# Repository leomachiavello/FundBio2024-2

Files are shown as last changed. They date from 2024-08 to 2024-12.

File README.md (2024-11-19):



# Fundamentos de Biodiseño - Equipo 08

## Descripción del curso
En el curso de Fundamentos de Biodiseño el estudiante será introducido a los métodos de diseño y desarrollo de tecnologías innovadoras con la finalidad de resolver una problemática que afecta a nuestra sociedad.
## 📋 Entregables
- [Entregable 1](https://github.com/leomachiavello/FundBio2024-2/blob/main/Entregables/Entregable_1.md)
- [Entregable 2](https://github.com/leomachiavello/FundBio2024-2/blob/main/Entregables/Entregable_2.md)
- [Entregable 3](https://github.com/leomachiavello/FundBio2024-2/blob/main/Entregables/Entregable_3.md)
- [Entregable 4](https://github.com/leomachiavello/FundBio2024-2/blob/main/Entregables/Entregable_4.md)
- [Entregable 5](https://github.com/leomachiavello/FundBio2024-2/blob/main/Entregables/Entregable_5.md)
- [Entregable 6](https://github.com/leomachiavello/FundBio2024-2/blob/main/Entregables/Entregable_6.md)
- [Entregable 7](https://github.com/leomachiavello/FundBio2024-2/blob/main/Entregables/Entregable_7.md)
- [Entregable 8](https://github.com/leomachiavello/FundBio2024-2/blob/main/Entregables/Entregable_8.md)
- [Entregable 9](https://github.com/leomachiavello/FundBio2024-2/blob/main/Entregables/Entregable_9.md)
## 👨‍🎓 Integrantes del equipo
### Leonardo Fabrizio Machiavello Díaz. **Coordinador General**
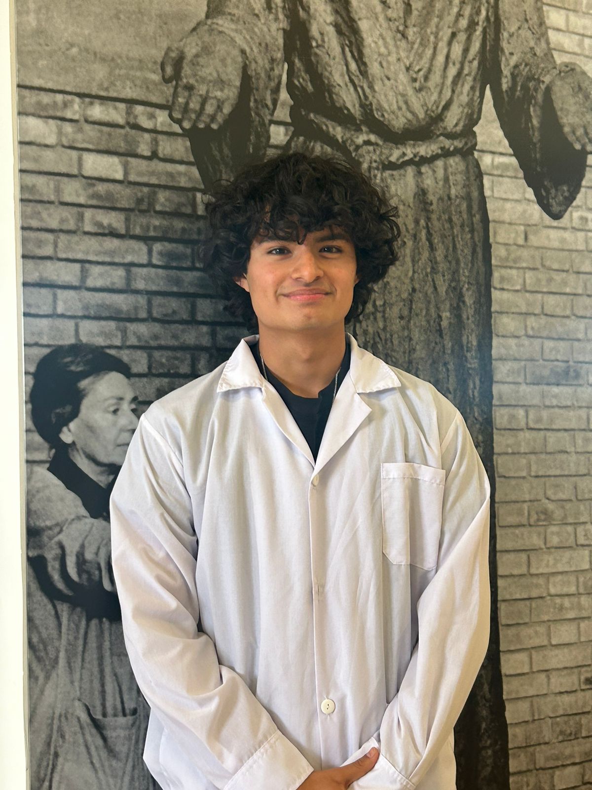
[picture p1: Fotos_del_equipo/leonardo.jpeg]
>

Estudiante de Ing. Biomédica con interés en la ingeniería clínica y el diseño industrial. Encargado de organizar al equipo asegurándose de que estén cumpliendo su deber, al igual que estar pendiente de que se cumplan las tareas del proyecto.

### Ana Paula Vela Velásquez. **Diseño 3D**
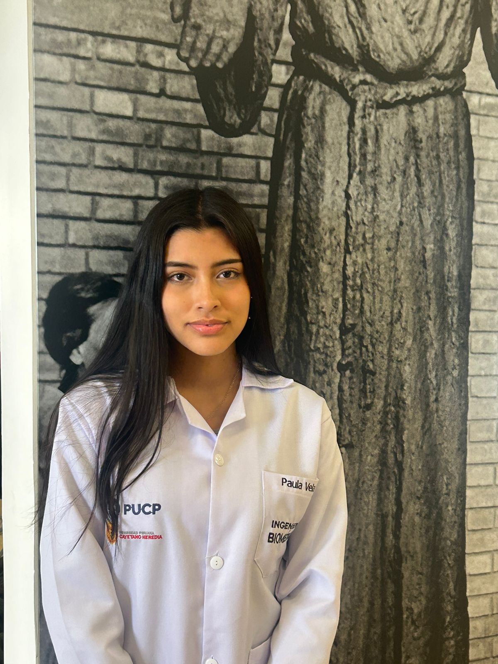
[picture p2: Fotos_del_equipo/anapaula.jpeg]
>

Estudiante de Ing. Biomédica con interés en la biomecánica aplicada para la rehabilitación.
Encargada de usar software enfocado en modelar diseños tridimensionales para aplicarlos a nuestro producto final.

### Luis Fernando Pingo Juárez. **Prototipado Electrónico**
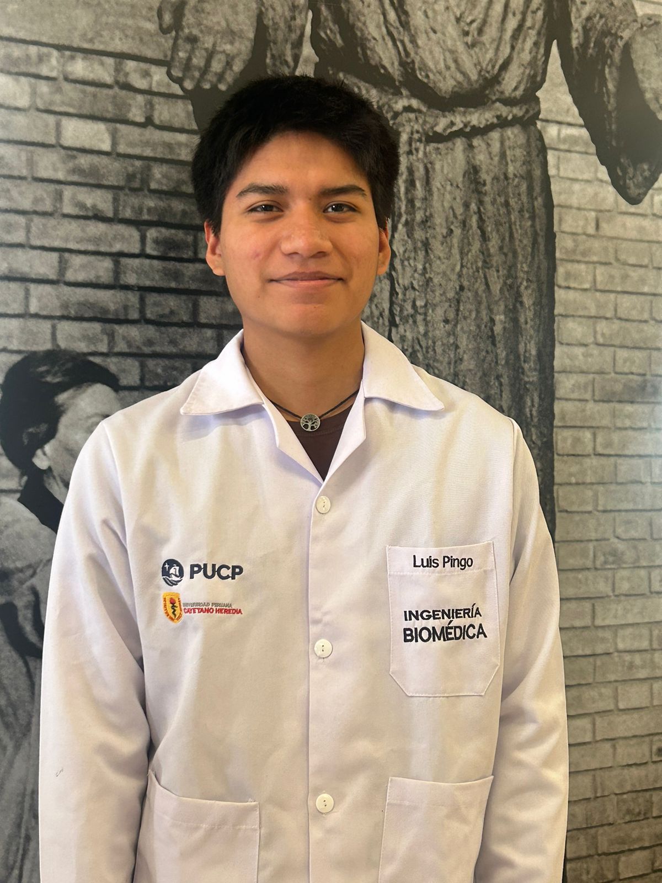
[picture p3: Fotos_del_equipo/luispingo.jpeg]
>

Estudiante de Ing. Biomédica con interés en la ingeniería de tejidos y . Encargado de desarrollar y construir prototipos de circuitos y dispositivos electrónicos, además de estar pendiente a la selección de componentes y el montaje de prototipos.

### Mateo Torres Ricalde. **Diseño electrónico**
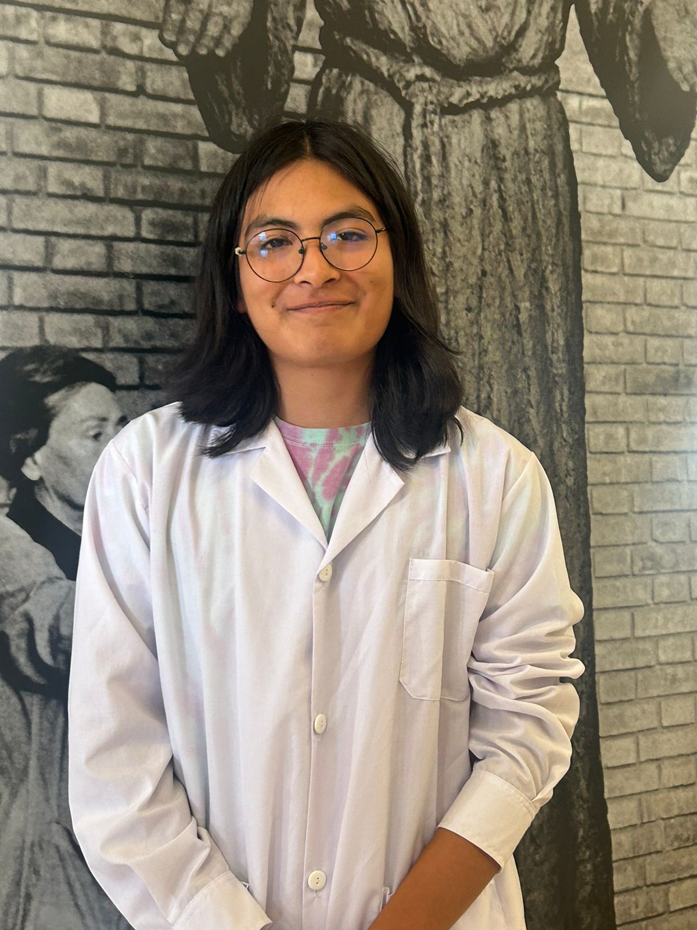
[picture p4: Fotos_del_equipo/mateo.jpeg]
>

Estudiante de Ing. Biomédica con interés en la biomecánica. Encargado de desarrollar el diseño y esquemas de los circuitos electrónicos utilizados, para conseguir la opción más adecuada al proyecto.

### Pedro Alonso Calderón Hidalgo. **Manufactura digital**
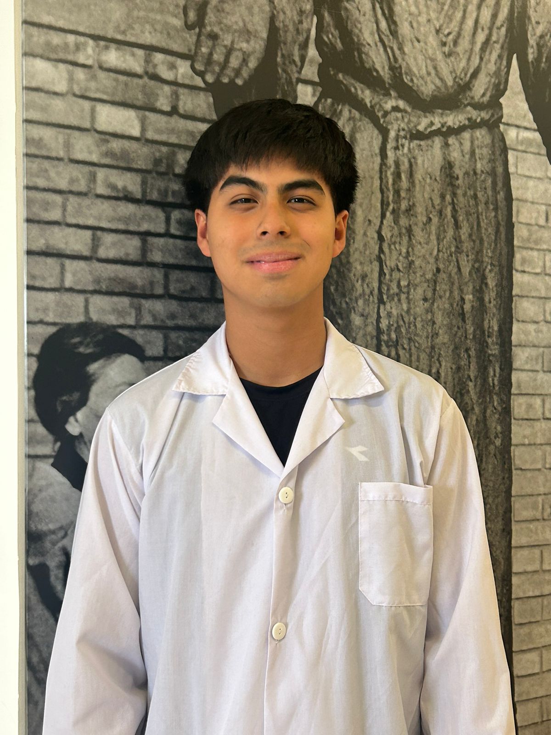
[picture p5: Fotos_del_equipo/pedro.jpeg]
>

Estudiante de Ingeniería Biomédica interesado en biomecánica y en mejorar dispositivos médicos. Diseña y produce prototipos con impresión 3D, asegurando precisión en especificaciones, gestionando manufactura y colaborando con el equipo de investigación.

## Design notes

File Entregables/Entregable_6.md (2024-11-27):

# Esquema electrónico final
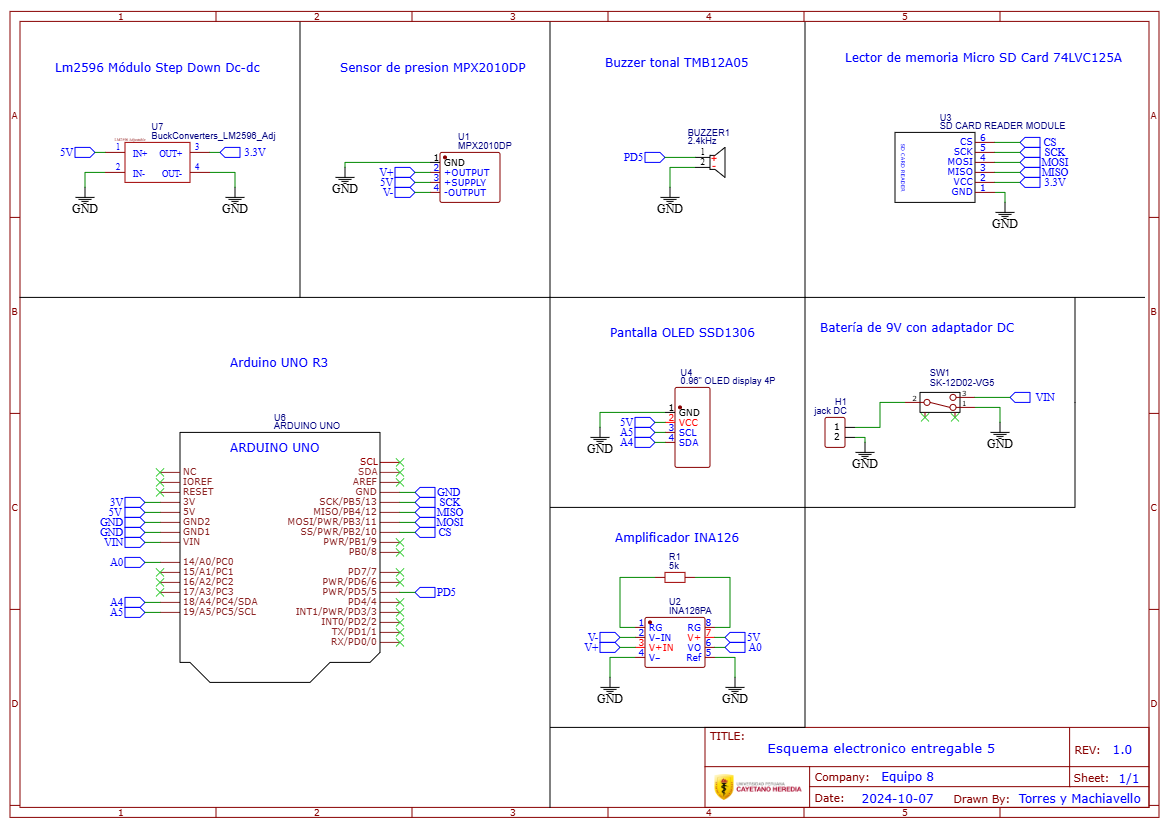
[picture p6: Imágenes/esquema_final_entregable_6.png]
esquema_final

# Ejecución del código Arduino
A partir del código mostrado en el siguiente inciso, hicimos una prueba usando los componentes básicos (sensor de presión, buzzer y amplificador). A partir de esto pudimos imprimir los datos de voltaje en el monitor serial del Arduino IDE, lo que nos permitió observar el cambio de señales de acuerdo a la presión ejercida.

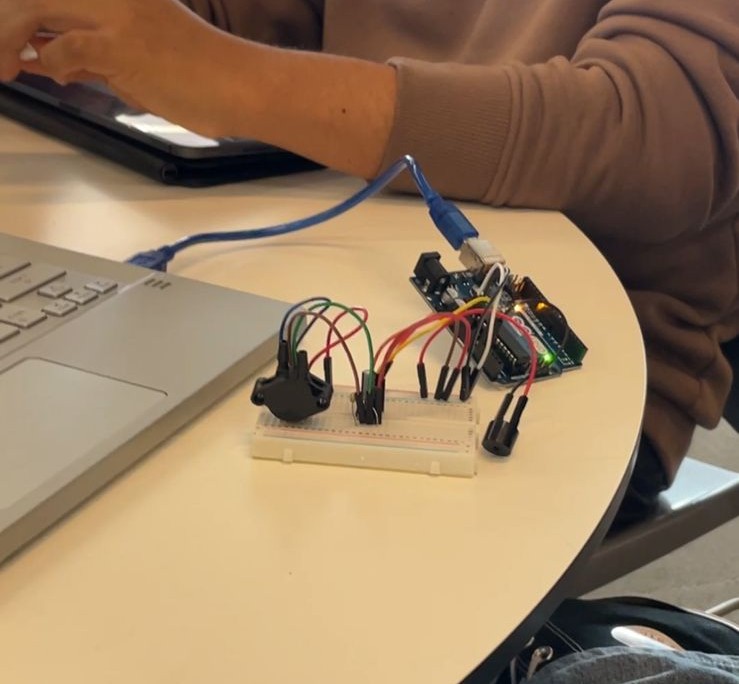
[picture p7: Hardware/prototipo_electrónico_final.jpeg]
prot_arduino

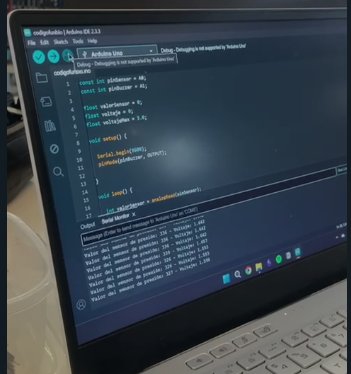
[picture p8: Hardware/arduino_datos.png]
datos_arduino

# Código Arduino
```
const int pinSensor = A0;
const int pinBuzzer = A1;

float valorSensor = 0;
float voltaje = 0;
float voltajeMax = 3.0;

void setup() {

  Serial.begin(9600);
  pinMode(pinBuzzer, OUTPUT);

}

void loop() {

  int valorSensor = analogRead(pinSensor);
  float voltaje = valorSensor * (5.0/1023.0);
  
  Serial.print("Valor del sensor de presión: ");
  Serial.print(valorSensor);
  Serial.print(" - Voltaje: ");
  Serial.println(voltaje, 3);

  if (voltaje >= voltajeMax){
    tone(buzzerPin, 1000);
  } else {
    noTone(buzzerPin);
  }

  delay(1000);

}
```
# Modelo 3D
## Vista explosionada
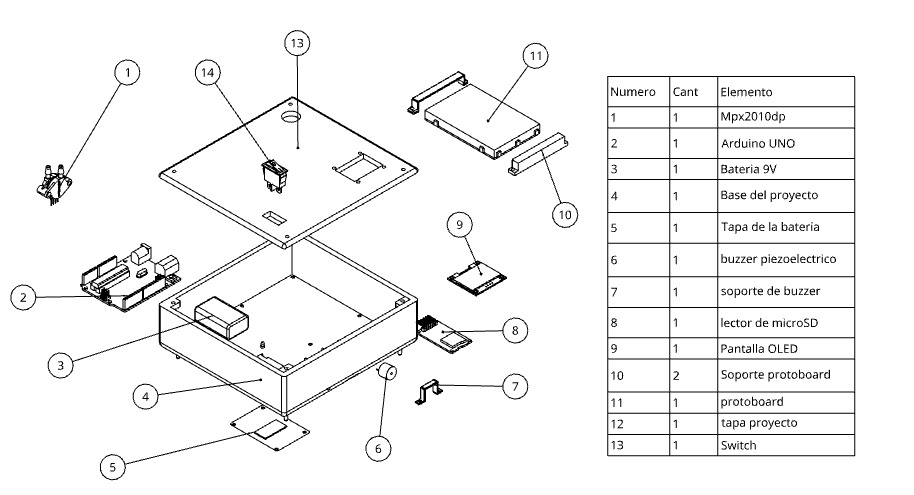
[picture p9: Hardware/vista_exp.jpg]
vista_exp

## Renderizados




# Diagrama de  flujo de datos (Arduino)
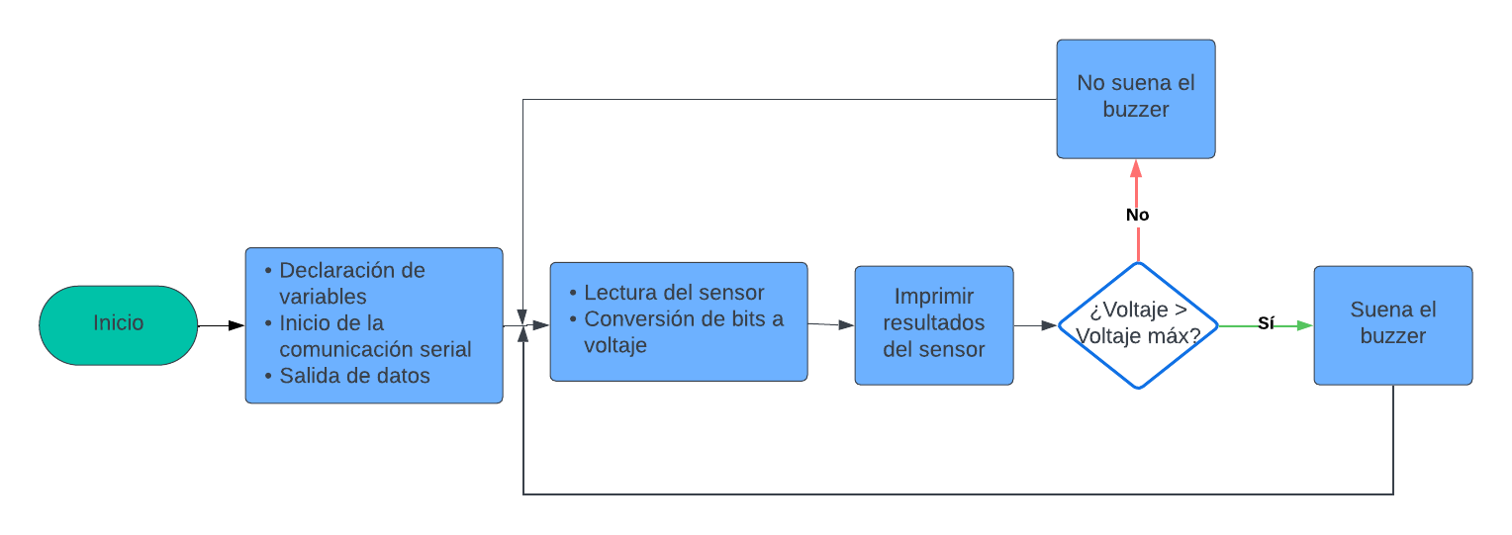
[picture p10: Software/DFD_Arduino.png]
DFD

# Reporte de pruebas
Funciones de los componentes:
-	Arduino Uno: se usa para procesar los datos recibidos por el sensor de presión diferencial y transformarlo en las variables que necesitamos.
-	Sensor de presión: mide la presión que ejerce el flujo de aire que es espirado por el paciente.
-	Buzzer: funciona como un indicador de que el procedimiento ha sido correcto o no.
-	Pantalla OLED: muestra información básica de los resultados del procedimiento.

Al evaluar la funcionalidad de los componentes que usaremos en el dispositivo, hemos verificado que la mayor parte de estos cumplen adecuadamente con su propósito, sin embargo, hemos identificado los siguientes aspectos en los que podemos mejorar:
-	Sensor de presión: es la pieza con más valor del prototipo, Además se tuvieron ciertas dificultades para poder implementarlo en el sistema, por lo que es necesario usarlo con cuidado para evitar dañar el componente y producir errores en la lectura.
-	Lector de tarjeta SD: es un componente difícil de conseguir en el país, por lo que se están evaluando otras posibilidades.
-	Regulador de voltaje (step down): Si bien fue considerado inicialmente como un componente importante, el lector de tarjeta SD tiene ya un regulador integrado, por lo que su uso termina siendo innecesario, lo que lleva a que este componente sea descartado del modelo final.

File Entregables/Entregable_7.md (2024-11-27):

# Esquema Electrónico
Esquema Final

# Ejecución del código Arduino 
Código usado en las pruebas para el sensor de presión. A partir de ello podemos transformar la presión ejercida a voltaje:
const int pinSensor1 = A0;
const int pinSensor2 = A1;

float valorSensor1 = 0;
float valorSensor2 = 0;

void setup() {
  
  Serial.begin(9600);
 
}

void loop() {

  int valorSensor1 = analogRead(pinSensor1);
  int valorSensor2 = analogRead(pinSensor2);

  Serial.print("Diferencia de presión: ");
  Serial.println(fabs(valorSensor1-valorSensor2));

  float voltaje = fabs(valorSensor1-valorSensor2) * (5.0/1023.0);
  Serial.print("Voltaje: ");
  Serial.print(voltaje * 1000, 3);
  Serial.println(" mV");

  float presion = voltaje / 0.009;
  Serial.print("Presión: ");
  Serial.print(presion);
  Serial.println(" kPa");

  delay(1000);

}
# Diagrama de flujo (Arduino)
Diagrama de flujo datos

# Reporte de pruebas
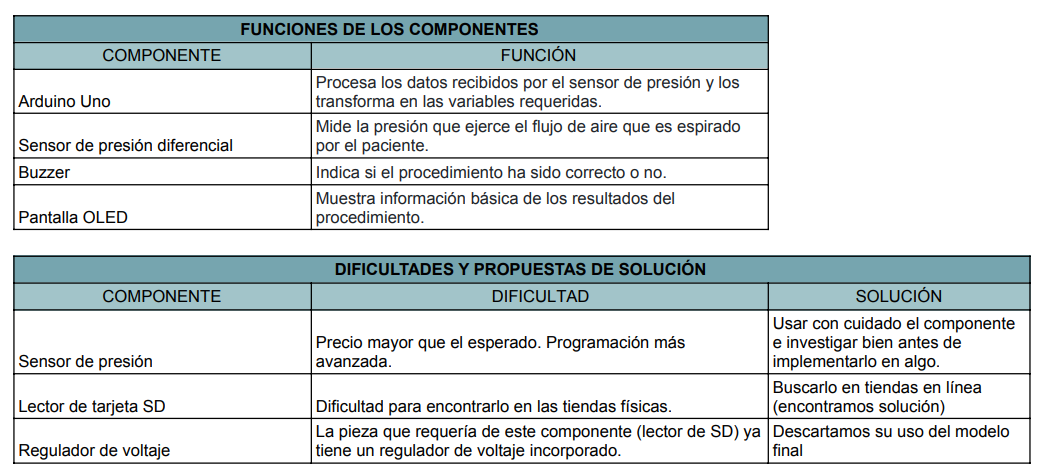
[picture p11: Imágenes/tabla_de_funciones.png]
tabla


# Impresión 3D
Base y tapa

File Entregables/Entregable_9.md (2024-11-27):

# Verificación de diseño (Software)

<table border="1">
  <tr>
    <th rowspan="2">Funcionalidad</th>
    <th colspan="2">Cumplimiento</th>
  </tr>
  <tr>
    <th>Sí</th>
    <th>No</th>
  </tr>
  <tr>
    <td>Recibe señales del sensor de presión</td>
    <td>X</td>
    <td></td>
  </tr>
  <tr>
    <td>Convierte las señales del sensor a presión</td>
    <td></td>
    <td>X</td>
  </tr>
  <tr>
    <td>Mide el tiempo de la prueba</td>
    <td>X</td>
    <td></td>
  </tr>
  <tr>
    <td>Genera un reporte rápido en la pantalla</td>
    <td>X</td>
    <td></td>
  </tr>
  <tr>
    <td>Genera un tabla con los datos en la tarjeta microSD</td>
    <td></td>
    <td>X</td>
  </tr>
</table>

# Verificación de diseño (Hardware)
| **Requerimiento de Diseño** | **Resultado del Test** |
|---|---|
| El dispositivo sumado al sistema de ajuste debe pesar máximo 300 gramos. | En suma de todos los componentes electrónicos el dispositivo cuenta con un peso de 260 gramos. |
| Debe tener una autonomía de 2 horas aproximadamente. | Con una batería de 9 voltios, se estima una duración aproximada de 10 horas tomando en cuenta el consumo de los elementos utilizados y el tiempo en que el dispositivo no es utilizado en ciclos de 32 minutos (2 de encendido, 30 de apagado). |
| Debe ser simple de usar para el usuario | El dispositivo cuenta con solo un switch de encendido y apagado. |
| Se debe seleccionar un sistema con boquilla desechable para que evitar contaminación en el dispositivo. | El sistema cuenta con una serie de boquillas desechables que permiten evitar cualquier tipo de contaminación. |
| El dispositivo de sonido buzzer proyecta un sonido a una frecuencia mayor o menor rango al señalizado por el Arduino Uno. | El dispositivo buzzer se activa a señal del Arduino Uno. |
| Mide la presión dada por la espiración del usuario. | El sensor de presión MPX2010DP mide la presión del usuario gracias a los amplificadores implementados |
| La interacción entre componentes se acciona mediante el protoboard y el Arduino Uno. | La interfaz entre los componentes otorga un resultado satisfactorio a través de la conexión con el protoboard señalizado al Arduino Uno. |
| El dispositivo es compacto y permite fácil transporte. | El dispositivo tiene unas dimensiones 157x147x49 mm que permiten su fácil transporte y un diseño compacto. |
| El dispositivo permite almacenar y transmitir datos. | El dispositivo permite almacenar datos gracias a la micro SD, transmitirlos gracias a la pantalla OLED y procesarlos gracias al Arduino Uno. |

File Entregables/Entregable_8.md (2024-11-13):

# Software
## [Códigos de prueba](https://github.com/leomachiavello/FundBio2024-2/tree/main/Software/c%C3%B3digos_prueba)
Agregamos códigos de prueba para cada componente electrónico (excluyendo el lector de tarjetas SD) con los cuales podemos realizar testeos. Estos se mostraron útiles sobre todo en la implementación de la pantalla de OLED y pruebas con la ganancia del amplificador INA126.
## [Borrador 1](https://github.com/leomachiavello/FundBio2024-2/tree/main/Software/borradores/borrador1)
Nuestra intención con este primer borrador fue la de integrar los principales componentes del proyecto. Hasta este punto todavía no teníamos la pantalla OLED, por lo que está excluída del código. Básicamente el código toma valores digitales del sensor y los pasa a voltaje haciendo uso de la ecuación $V=\frac{5.0}{1023.0}$ donde 5.0 representa el voltaje de la fuente y 1023.0 el número de bits máximo de la señal digital del Arduino. 
## [Borrador 2](https://github.com/leomachiavello/FundBio2024-2/tree/main/Software/borradores/borrador2)
En este segundo borrador implementamos la pantalla OLED junto a los demás componentes haciendo uso de librerías externas como Adafruit_GFX y Adafruit_SSD1306. En la pantalla OLED se muestran los valores de voltaje.
## [Borrador 3](https://github.com/leomachiavello/FundBio2024-2/tree/main/Software/borradores/borrador3)
En el tercer borrador implementamos un módulo en el código cuya función es la de promediar 10 valores en el lapso de un segundo de las señales amplificadas del sensor. Esto se hizo con el objetivo de reducir la variación de valores que se crea por el amplificador. 
## [Borrador 4](https://github.com/leomachiavello/FundBio2024-2/tree/main/Software/borradores/borrador4)
Finalmente en este borrador hemos juntado todo lo previamente mencionado e implementado un cronómetro que se activa al momento que el voltaje sobrepasa cierto límite. También en este código podemos generar un reporte del voltaje máximo y un promedio de los voltajes obtenidos para obtener información sobre la prueba.
## Parámetros de la espirometría
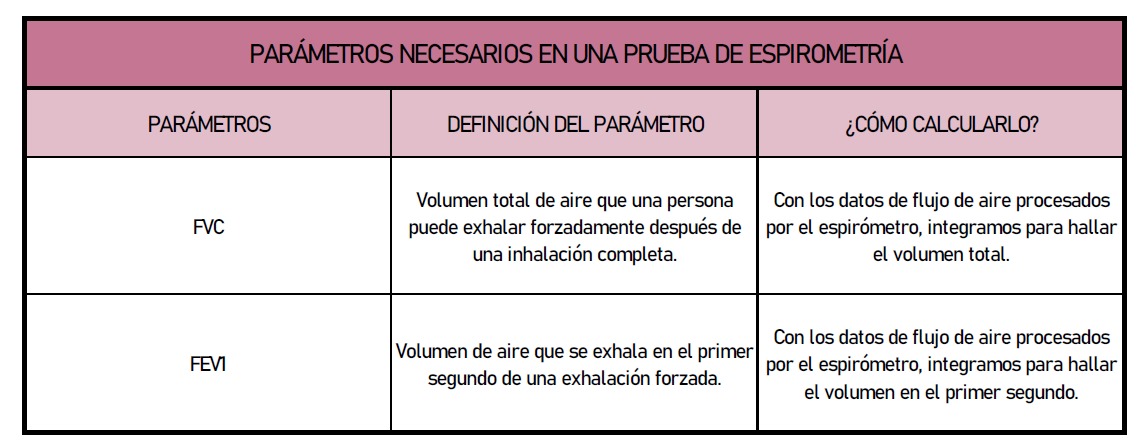
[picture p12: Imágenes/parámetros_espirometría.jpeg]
parámetros


Existen una serie de parámetros relacionados con la espirometría como el FVC, FEV6, FEV1 y PEF que sirven para detectar y clasificar enfermedades respiratorias. Entre los mencionados destacan el FVC y FEV1, ya que con estos se obtiene un índice con el que se clasifica una enfermedad respiratoria como obstructiva o restrictiva, lo que se ajusta a los objetivos de este proyecto.
# Hardware
## [Amplificador INA126](https://github.com/leomachiavello/FundBio2024-2/blob/main/Hardware/Datasheets/INA126_datasheet.pdf)
La fórmula de la ganancia de este amplificador en específico es la siguiente: 
$G=5+\frac{80k\Omega}{R_G}$. Actualmente la resistencia que estamos empleando para la ganancia es de $1k\Omega$ por lo que nuestra ganancia resultante es de 85. Aunque esta ganancia no es tan pequeña, tampoco es ideal para nuestro caso ya que el rango de voltajes del sensor se encuentra entre los 0 a 25mV, por lo que lo ideal será emplear una ganancia de 1000 que sea estable. Nuestras opciones de solución son las siguientes:
### Usar una resistencia menor 
Esta solución implicaría una mayor inestabilidad en la señal brindada por el amplificador, por lo que también se tendrían que implementar filtros de ruido usando capacitores y pequeños circuitos RC.
### Usar un amplificador extra
Esta solución sería un poco más costosa que la anterior, pero sería más simple. El amplificador que planeamos implementar es el **LM358**, el cual es económico y simple de usar. Para ajustar la ganancia se hace uso de dos resistencias, siguiendo la siguiente fórmula: $G=1+\frac{R_f}{R_{in}}$.
## Modelado 3D
Para este semana hemos logrado culminar al 100% nuestro modelo 3D, arreglamos las correciones indicadas por el profesor Andoni Molina y enviamos nuestras 5 piezas a imprimir, estamos a la espera que nos avisen para poder recogerlas. Acá tenemos algunas imagenes de nuestro modelo ensamblado, tenemos los [planos](https://github.com/leomachiavello/FundBio2024-2/tree/main/Hardware/Planos%20finales) de las 5 piezas corregidos y actualizados al igual que los [archivos stl](https://github.com/leomachiavello/FundBio2024-2/tree/main/Hardware/Archivos%20STL).
### Vistas isométricas del ensamblado
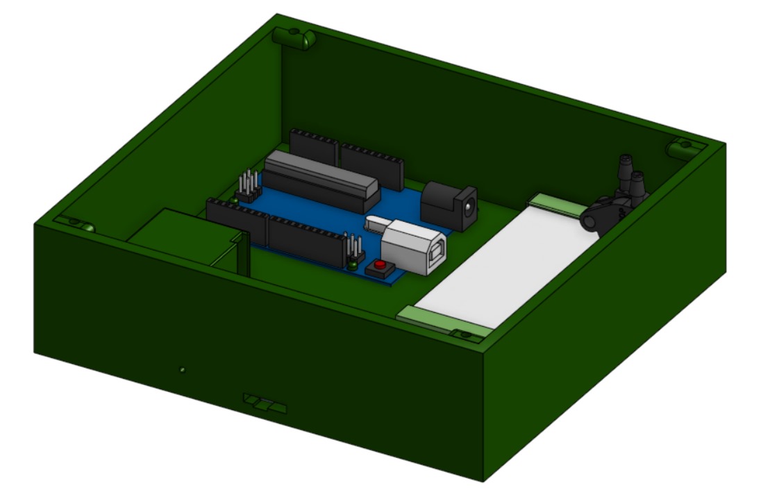
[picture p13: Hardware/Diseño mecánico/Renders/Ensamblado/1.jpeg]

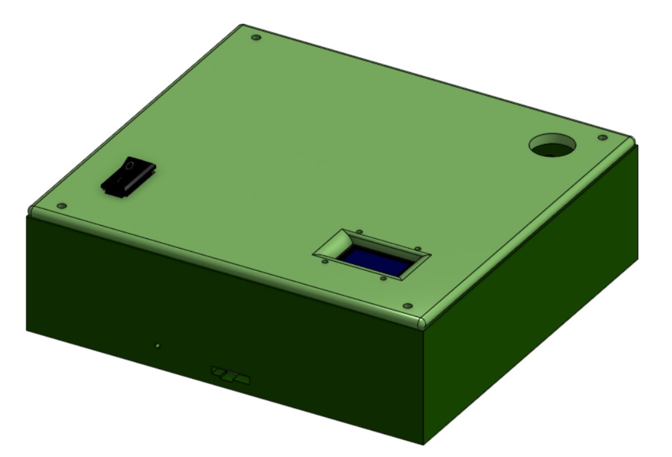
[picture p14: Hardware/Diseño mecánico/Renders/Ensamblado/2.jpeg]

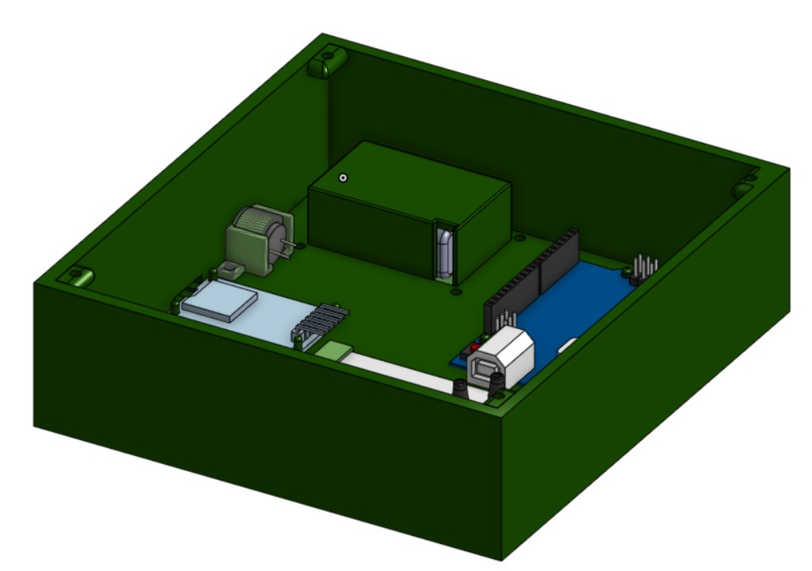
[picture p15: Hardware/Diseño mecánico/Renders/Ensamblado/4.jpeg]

### Vista superior
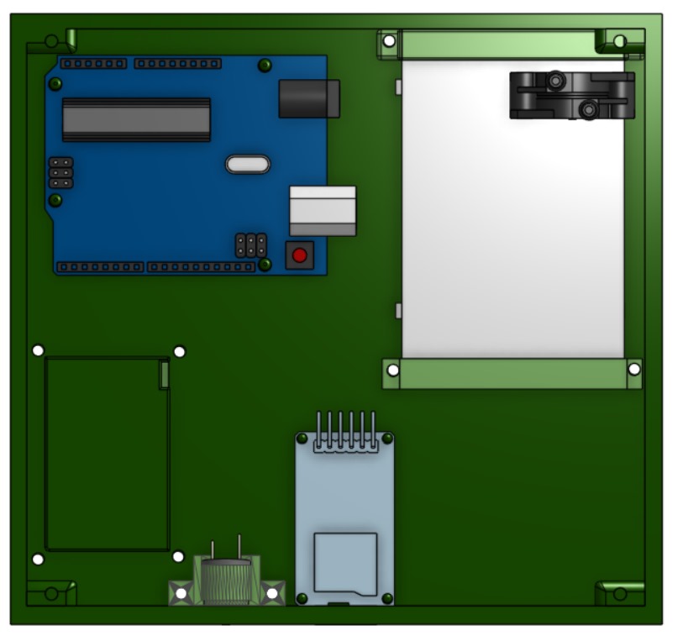
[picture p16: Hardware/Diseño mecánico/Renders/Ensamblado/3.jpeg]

### Vista inferior
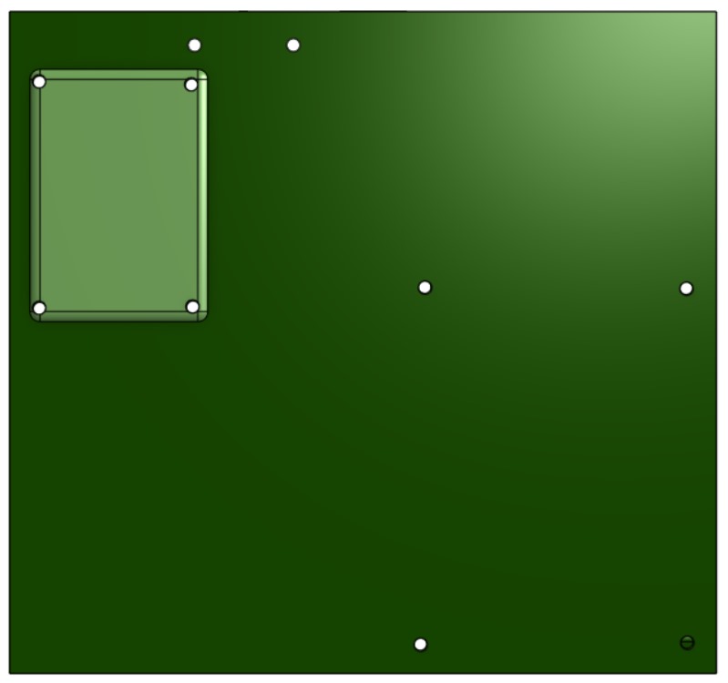
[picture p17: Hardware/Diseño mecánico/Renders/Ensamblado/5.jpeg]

## [Esquema electrónico](https://github.com/leomachiavello/FundBio2024-2/blob/main/Hardware/Dise%C3%B1o%20electr%C3%B3nico/Esquema_electr%C3%B3nico.pdf)
Actualizamos el esquema electrónico previo, eliminando el regulador de voltaje que no fue necesario para el proyecto e incluyendo el segundo amplificador LM358.

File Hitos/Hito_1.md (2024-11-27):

# Lungie
## Propuesta de solución
**Problemática:** Deficiencia en el diagnóstico de enfermedades respiratorias obstructivas en las zonas de escasos recursos en Perú. Aproximadamente el 64% de los diagnósticos en el país son erróneos, lo cual se vuelve un problema alarmante considerando la alta prevalencia de enfermedades respiratorias obstructivas y la escasez de espirómetros, especialmente en el sector público [1,2].

**Propuesta de solución:** Espirómetro portable de bajo costo que contribuya a la detección de enfermedades respiratorias obstructivas (EPOC, asma, etc). Para uso exclusivo de un profesional de la salud, puede usarse en diversos ambientes debido a su portabilidad.
## Esquema de funciones
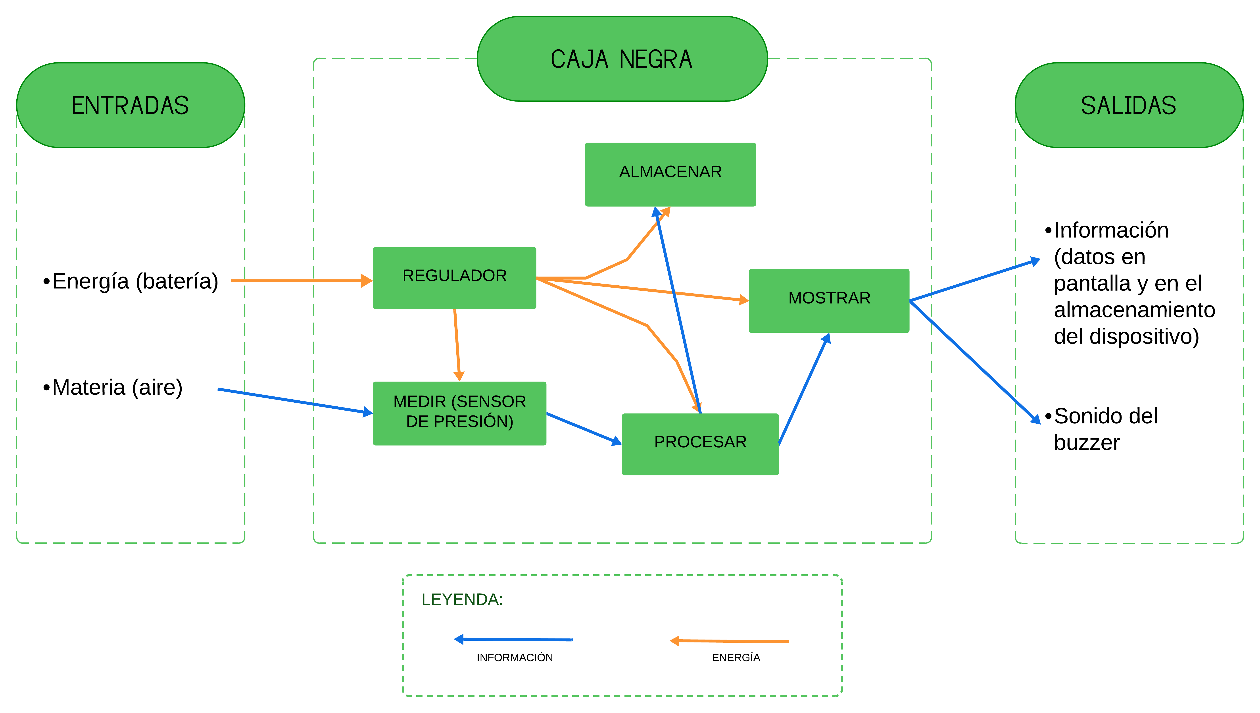
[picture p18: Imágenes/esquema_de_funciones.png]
esquema_funciones

## Matriz morfológica
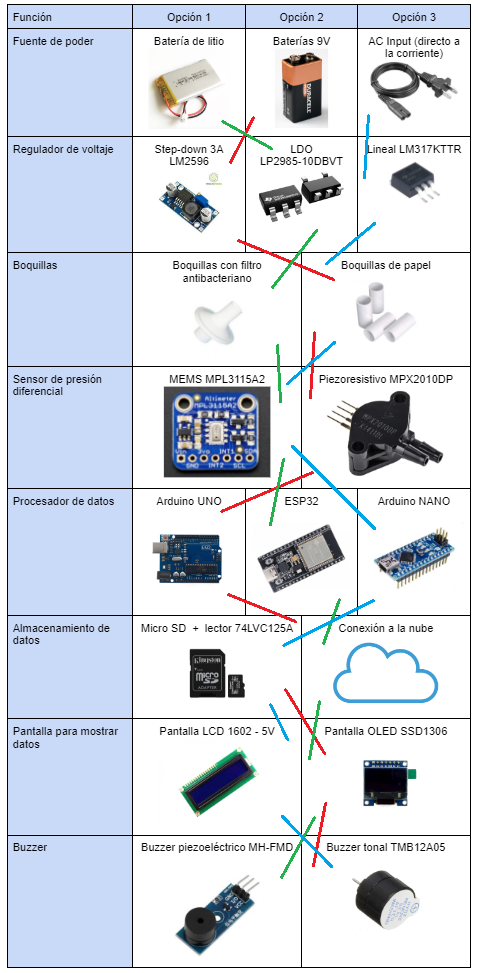
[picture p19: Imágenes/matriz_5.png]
matriz_morfológica

## Tabla de valoración
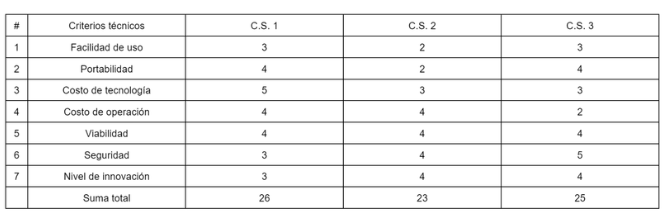
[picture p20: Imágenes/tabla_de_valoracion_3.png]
tabla_de_valoración

## Boceto final
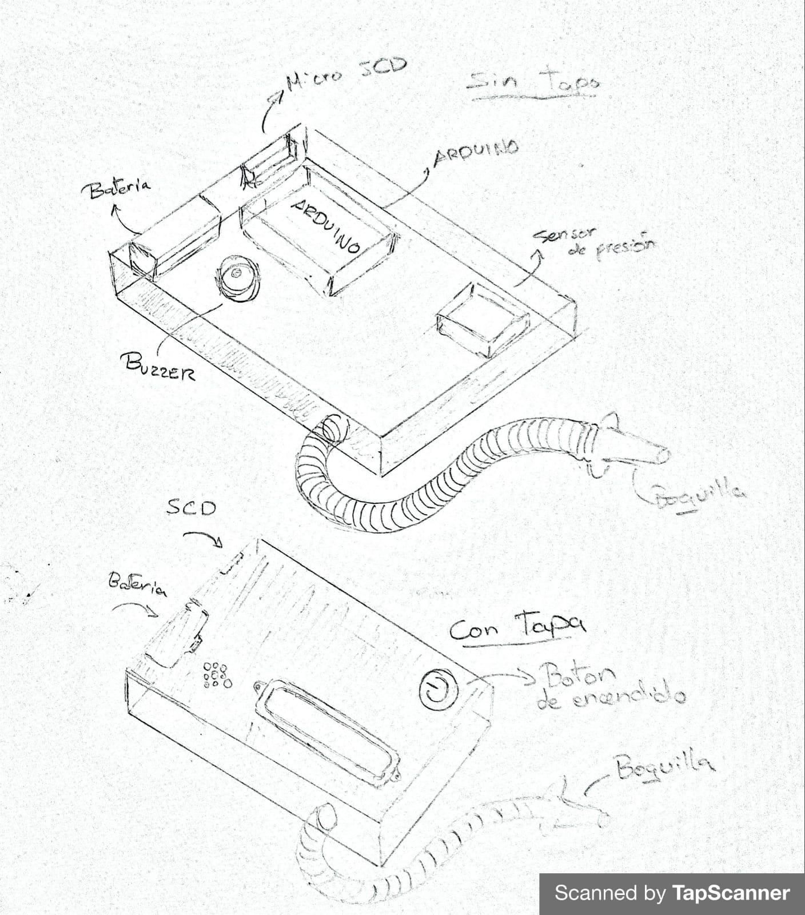
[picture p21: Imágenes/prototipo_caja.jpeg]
caja

## Modelo 3D
### Vista explosionada
vista_exp
### Planos y vistas de piezas a imprimir
#### Planos
- [Base](https://github.com/leomachiavello/FundBio2024-2/blob/main/Hardware/Dise%C3%B1o%20mec%C3%A1nico/Planos%20Hito%201/Base%20Plano.pdf) 
- [Tapa](https://github.com/leomachiavello/FundBio2024-2/blob/main/Hardware/Dise%C3%B1o%20mec%C3%A1nico/Planos%20Hito%201/Tapa%20Plano.pdf)
- [Soporte Buzzer](https://github.com/leomachiavello/FundBio2024-2/blob/main/Hardware/Dise%C3%B1o%20mec%C3%A1nico/Planos%20Hito%201/Soporte%20Buzzer%20Plano.pdf)
- [Soporte Protoboard](https://github.com/leomachiavello/FundBio2024-2/blob/main/Hardware/Dise%C3%B1o%20mec%C3%A1nico/Planos%20Hito%201/Soporte%20Protoboard%20Plano.pdf)
- [Tapa batería](https://github.com/leomachiavello/FundBio2024-2/blob/main/Hardware/Dise%C3%B1o%20mec%C3%A1nico/Planos%20Hito%201/Tapa%20Bater%C3%ADa.pdf)
#### Impresión CURA
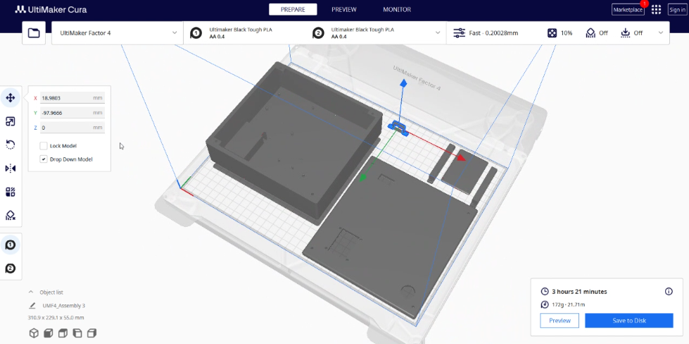
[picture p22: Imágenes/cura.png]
cura

#### Tabla de impresión
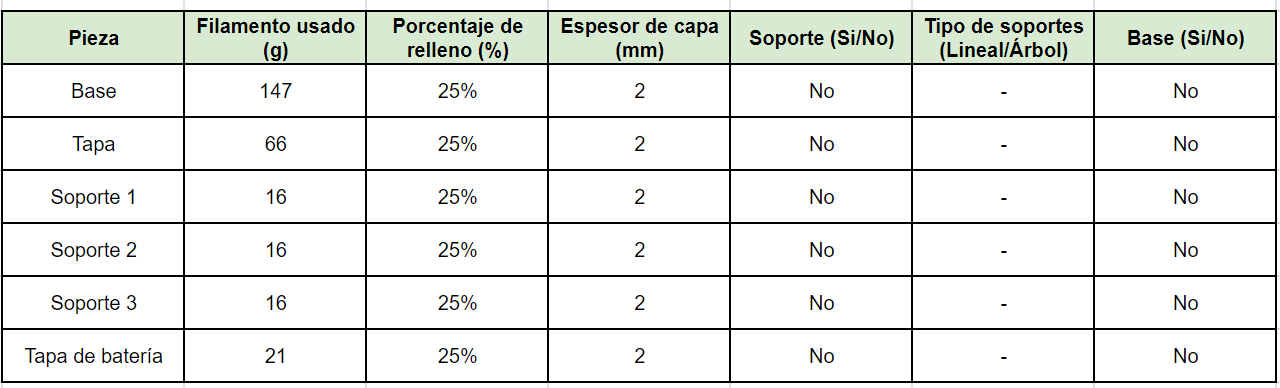
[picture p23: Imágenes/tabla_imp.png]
tabla

## Diseño esquemático del circuito
diseño esquematico
## Prototipo electrónico
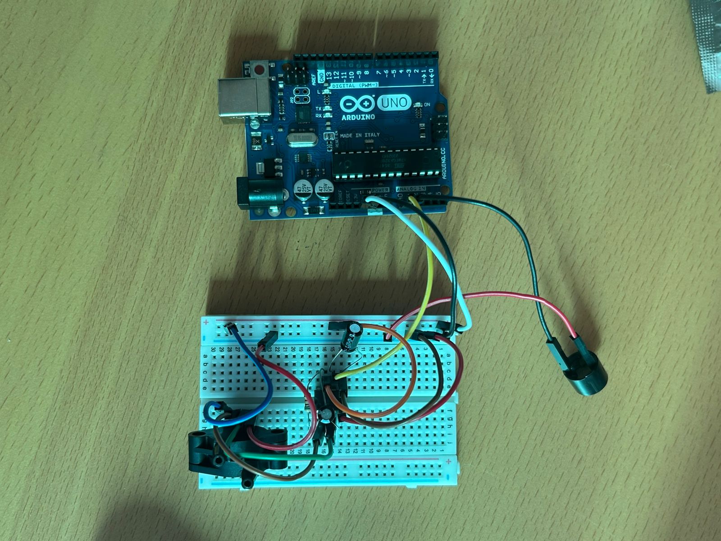
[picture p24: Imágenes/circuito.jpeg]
prototipo

## Referencias
1. Centro Nacional de Epidemiología, Prevención y Control de Enfermedades, “BOLETÍN EPIDEMIOLÓGICO DEL PERÚ”, 2023.
2. S. P. de Neumología, “Guía Peruana de EPOC -2016”, 2016.

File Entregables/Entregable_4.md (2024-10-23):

# Caja negra
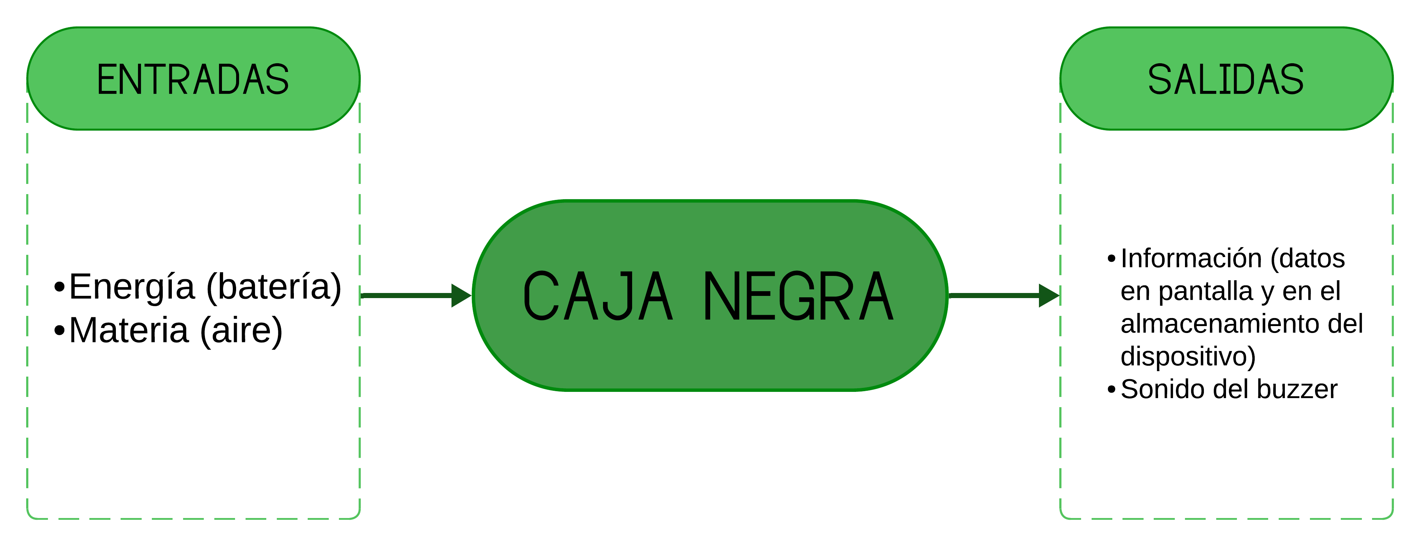
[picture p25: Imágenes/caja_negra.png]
caja_negra

# Esquema de funciones
esquema_funciones

**Regulador** - para distribuir la energía a los diferentes componentes que la necesitan.

**Medir** - el sensor de presión registra y mide la materia (aire) ingresado.

**Procesar** - con el microprocesador realizamos los cálculos correspondientes y se pone en los términos que necesitamos para evaluar si la muestra ha sido óptima.

**Mostrar** - los resultados se muestran en la pantalla (pequeños datos) o mediante el buzzer, de acuerdo al caso. Esto es solo una muestra rápida para saber si el procedimiento se ha realizado correctamente.

**Almacenar** - se guardan los datos para poder visualizarlos después en un dispositivo más complejo y profundizar en el resultado. 

# Matriz morfológica
matriz_morfológica
- C.S. 1: Rojo
- C.S. 2: Azul
- C.S. 3: Verde
# Tabla de valoración
tabla_de_valoración
# Conclusión
A partir de una valoración de los parámetros que consideramos más importantes, nos decidimos por el concepto de solución número 3. Los componentes elegidos para este concepto permiten una buena portabilidad para nuestro propósito al igual que una buena eficiencia energética. Lo que quisimos priorizar sobre todo fue la precisión del examen para que el paciente tenga una buena base por la cual guiarse para una posible patología respiratoria.
# Bocetos del prototipo
## Espirómetro de caja
caja
Este prototipo que planteamos tiene una relativa portabilidad, sin llegar a ser de mano. Es un tamaño ideal para un uso en campañas de salud y para visitas médicas. El formato de caja permite una mejor distribución de los componentes en la carcasa del dispositivo. 
## Espirómetro portable de gatillo
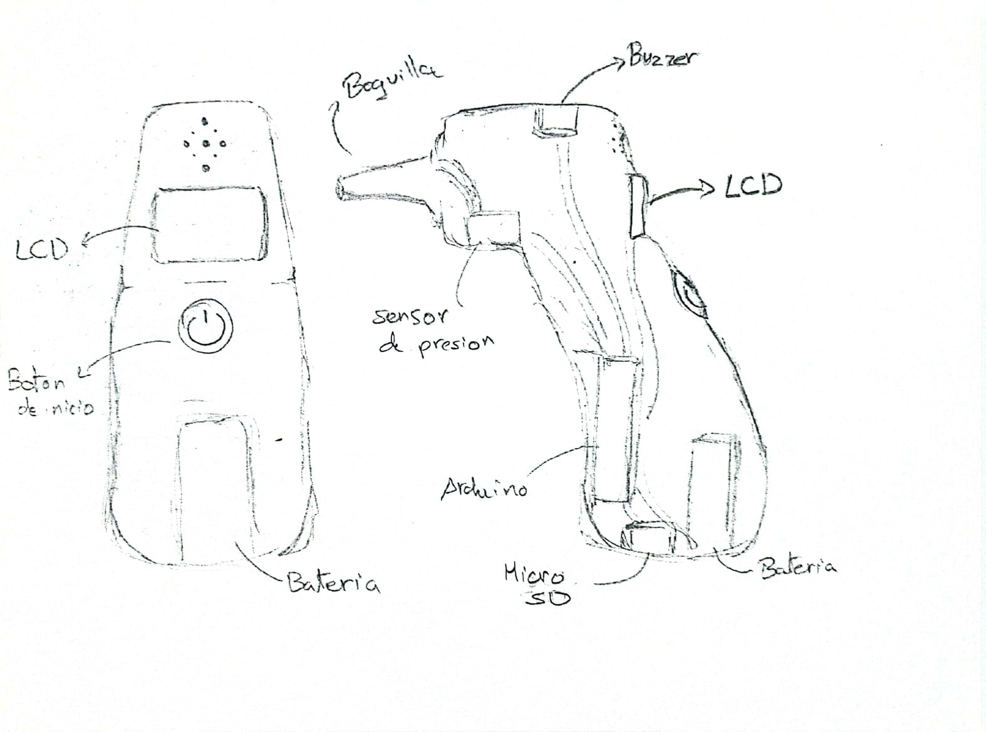
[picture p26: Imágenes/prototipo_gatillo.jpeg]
gatillo

El prototipo con forma de gatillo permite una mayor portabilidad pudiendo usarse de mano. Esta particularidad lo hace perfecto para un uso más amigable, sencillo y rápido en el entorno médico.
## Espirómetro de cajón compacto
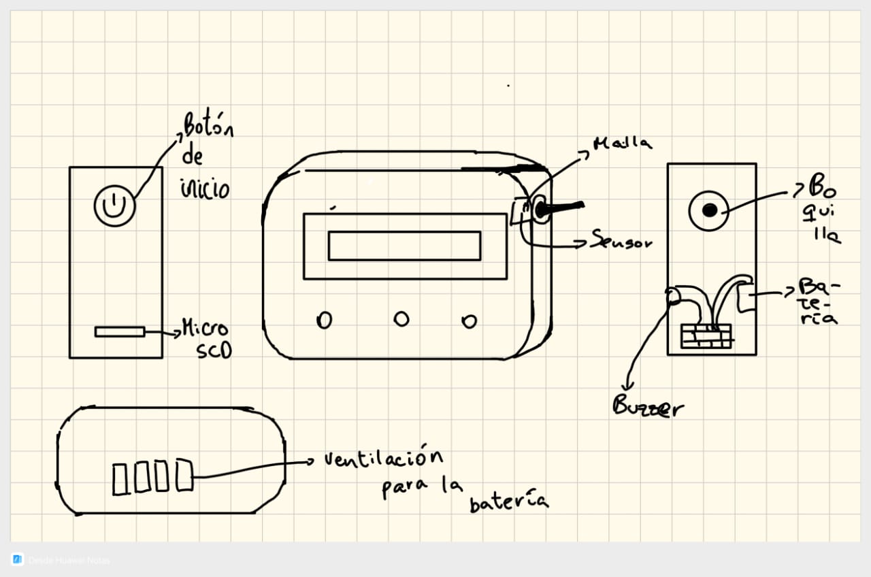
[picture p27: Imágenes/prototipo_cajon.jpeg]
cajon

Al igual que el prototipo de caja, esta forma de dispositivo también nos permite un buen funcionamiento de los componentes elegidos. Esto también le agrega una robustez al producto que será útil en contextos rurales donde el transporte continuo es necesario.

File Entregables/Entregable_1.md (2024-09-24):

# Análisis Temático: Open hardware
El término open hardware proveniente del término “Open” de libre y “Hardware” el cual son todos los componentes físicos que conforman un dispositivo; es la libre información del diseño y especificaciones de dispositivos publicada para el estudio, modificación y distribución legal. Al ser libre para el público, este permite a las personas aprender y desarrollar nuevas ideas y productos. Además de la reducción de costos y mayor libertad al no depender de proveedores de hardware.
# Contexto de la problemática
En la actualidad, Perú enfrenta una serie de problemas relacionados con el servicio sanitario del país. Entre los factores que originan la situación mencionada, destacan deficiencias como la escasez de centros de salud, falta de personal calificado, equipos obsoletos y hospitales saturados.
Los factores mencionados dificultan y limitan el diagnóstico de enfermedades, especialmente en los sectores con más carencias en el país. Las enfermedades respiratorias obstructivas, como el asma, EPOC y enfisema; son algunas de las cuales causan más problemas en la población debido a la dificultad de diagnóstico frente a su alta prevalencia. En Latinoamérica, el asma alcanza una prevalencia de 17%, con fluctuaciones que oscilan entre 5 y 30%. En 2023, en Perú se registraron 1253 casos de asma [1]. Por otro lado, a nivel global, la EPOC es la tercera causa de muerte y la séptima causa de mala salud.
Para diagnosticar enfermedades respiratorias es necesaria la espirometría, pero se utiliza con poca frecuencia. A pesar del progreso en la disponibilidad de espirómetros en nuestro país y de la constante formación de especialistas en Neumología en los últimos años, aún continúa siendo insuficiente accesibilidad a estos recursos, especialmente en el ámbito público [2]. Esto ha llevado a una alarmante cifra de diagnósticos erróneos (64% de los casos), lo que es una prueba de la urgencia de mejora en este aspecto.

## Diagrama ishikawa 
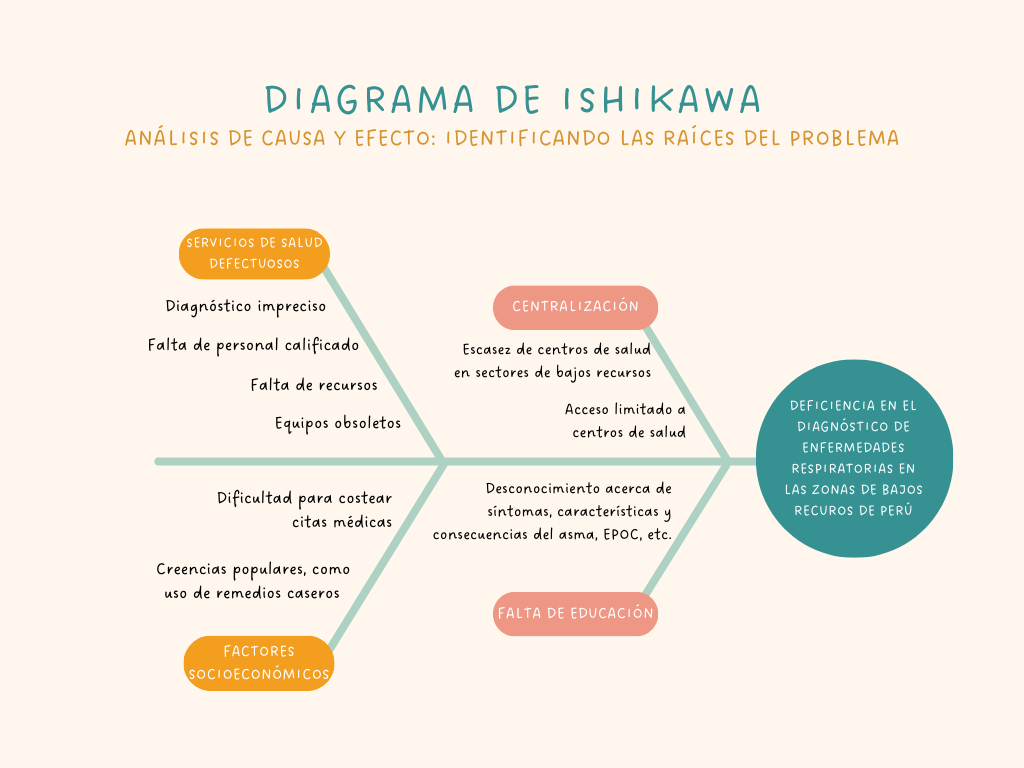
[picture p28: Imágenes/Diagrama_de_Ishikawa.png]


## Estado del arte

### Espirómetro electrónico portátil con visualización en dispositivo móvil [[3](https://moodle2.utp.edu.co/index.php/revistaciencia/article/view/18451/14631)]
En  este  trabajo  se  presenta  el  diseño  de  un sistema  de  espirometría  portable  de  bajo  costo  usando  como interfaz de usuario un dispositivo móvil con sistema operativo Android. El sistema de sensado de la capacidad respiratoria está basado en el espirómetro tipo Fleisch, el cual usa un sensor de presión,  proporcionando  mayor durabilidad  del  producto  en comparación  de  los  espirómetros  de  turbina.  El  hardware electrónico,  y la  interfaz  gráfica de  usuario (elaborada  para el sistema operativo Android utilizando el IDE de processing) se describen en detalle. El costo   estimado del dispositivo realizado  es  inferior  a  los  90 USD. El  prototipo elaborado permite  el  fácil  diagnóstico  y  seguimiento  de  enfermedades respiratorias, mejorando así la calidad de vida de los usuarios. 

Para  probar  el  prototipo  desarrollado  y  verificar  su  correcto funcionamiento,   se   realizaron   pruebas   en   9   voluntarios obteniendo mediciones simultáneas con el prototipo realizado y con un espirómetro de mesa comercial de la marca MicroLab™, el  cual  se  usa  como  referencia. Los resultados obtenidos muestran que los valores obtenidos con ambos dispositivos son bastante similares, lo cual valida el correcto funcionamiento del dispositivo desarrollado.

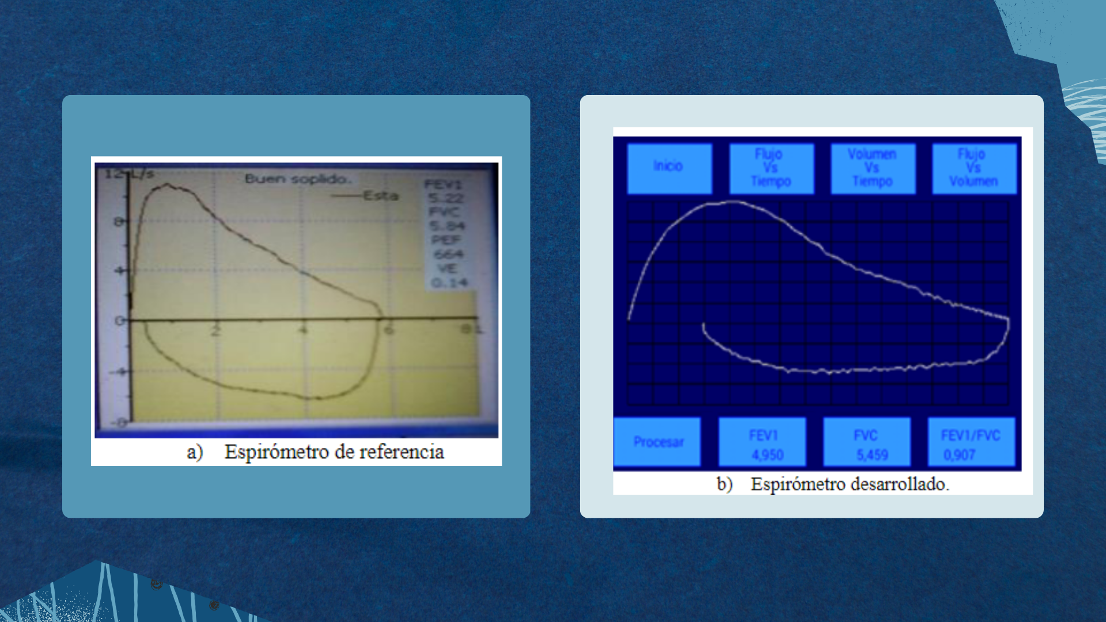
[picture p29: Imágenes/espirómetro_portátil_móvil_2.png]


### Espirómetro de turbina de código abierto para la evaluación de la función respiratoria [[4](https://ieeexplore-ieee-org.ezproxybib.pucp.edu.pe/document/10608659)]
Se presenta un espirómetro de turbina de bajo coste y fácil de usar que mide la frecuencia respiratoria y los periodos inspiratorios y espiratorios medios, identificando los momentos de transición entre la inspiración y la espiración. Además, el dispositivo tiene el potencial de permitir la derivación de curvas de flujo-volumen características de la espirometría, lo que permite el cálculo de importantes indicadores respiratorios como la FVC y el FEV1, cruciales para el diagnóstico y seguimiento de patologías respiratorias. El dispositivo está compuesto principalmente por piezas impresas en 3D y utiliza componentes electrónicos simples. Se realizaron seis ensayos con errores bajos en la determinación de la frecuencia respiratoria y los períodos inspiratorio y espiratorio promedio, cuando se los compara con un método de referencia, el cronómetro. Este trabajo establece oportunidades futuras para estudios que busquen el refinamiento de algoritmos ideados para obtener las curvas flujo-volumen características de la espirometría, que permitan la extracción de indicadores respiratorios importantes.

### Espirómetro digital con aplicación móvil para asmáticos [[5](https://ieeexplore-ieee-org.ezproxybib.pucp.edu.pe/document/9467250)]
Se ha desarrollado un espirómetro digital con una aplicación móvil que puede ayudar a los pacientes asmáticos a autocontrolarse y hacer un seguimiento de su estado pulmonar. El dispositivo se puede dividir en tres partes: hardware, aplicación móvil y base de datos. El hardware consta de NodeMCU, un sensor de presión y una boquilla. La señal analógica del sensor se convirtió en digital por el NodeMCU y se envió de forma inalámbrica mediante wifi a un teléfono inteligente y se almacenó en una base de datos. Se ha reclutado a un sujeto normal de 24 años para realizar una prueba de tres categorías de gravedad mediante la aplicación móvil. Las categorías son normal, moderada y grave, y el resultado mostró la gravedad correctamente de acuerdo con la categoría en comparación con la teoría.

# Fuentes de información
1. Centro Nacional de Epidemiología, Prevención y Control de Enfermedades, “BOLETÍN EPIDEMIOLÓGICO DEL PERÚ”, 2023.
2. S. P. de Neumología, “Guía Peruana de EPOC -2016”, 2016.
3. R. A. Díaz-Suarez; V. A. Pabón-Castillo; S. F. Vera-Medina; A. F. Gómez Chacón (2019) Espirómetro Electrónico Portátil con Visualización en Dispositivo Móvil
4. Mariana Bernardino; Hugo Plácido Da Silva (2024) An Open Source Mask-based Turbine Spirometer for Respiratory Function Assessment. https://ieeexplore-ieee-org.ezproxybib.pucp.edu.pe/document/10608659 
5. Arif Amiruddin Yaacob; Noreha Abdul Malik; Othman Omran Khalifa (2021) Digital Spirometer with a Mobile Application for Asthmatic Patient. https://ieeexplore-ieee-org.ezproxybib.pucp.edu.pe/document/9467250

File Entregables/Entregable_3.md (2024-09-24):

# Problemática
## Contexto
En la actualidad, Perú enfrenta una serie de problemas relacionados con el servicio sanitario del país. Entre los factores que originan la situación mencionada, destacan deficiencias como la escasez de centros de salud, falta de personal calificado, equipos obsoletos y hospitales saturados.
Los factores mencionados dificultan y limitan el diagnóstico de enfermedades, especialmente en los sectores con más carencias en el país. Las enfermedades respiratorias obstructivas, como el asma, EPOC y enfisema; son algunas de las cuales causan más problemas en la población debido a la dificultad de diagnóstico frente a su alta prevalencia. En Latinoamérica, el asma alcanza una prevalencia de 17%, con fluctuaciones que oscilan entre 5 y 30%. En 2023, en Perú se registraron 1253 casos de asma [1]. Por otro lado, a nivel global, la EPOC es la tercera causa de muerte y la séptima causa de mala salud.

Para diagnosticar enfermedades respiratorias es necesaria la espirometría, pero se utiliza con poca frecuencia. A pesar del progreso en la disponibilidad de espirómetros en nuestro país y de la constante formación de especialistas en Neumología en los últimos años, aún continúa siendo insuficiente accesibilidad a estos recursos, especialmente en el ámbito público [2]. Esto ha llevado a una alarmante cifra de diagnósticos erróneos (64% de los casos), lo que es una prueba de la urgencia de mejora en este aspecto.

asma_estadística

## Definición de problema
El problema que se abordará es el de la deficiencia en el diagnóstico de enfermedades respiratorias obstructivas en las zonas de escasos recursos en Perú.

## Impacto 
Este problema afecta a los usuarios en diversos aspectos. La falta de diagnóstico oportuno impide iniciar un tratamiento adecuado a tiempo, lo que puede agravar la enfermedad y aumentar el riesgo de complicaciones. Además, los síntomas de las enfermedades respiratorias, como dificultad para respirar, tos crónica y fatiga, pueden afectar significativamente la calidad de vida de los pacientes, limitando sus actividades diarias y su participación social.

# Propuesta de solución
## Descripción de la solución
Espirómetro portable de bajo costo que contribuya a la detección de exámenes correctamente realizados haciendo uso de sensores de presión, un dispositivo buzzer (para ser usado de alerta por el uso correcto o incorrecto por el uso del usuario) y un microcontrolador para la gestión de datos. Nuestro dispositivo busca directamente solucionar el problema de la deficiencia en el diagnóstico, la precisión y diferenciación de enfermedades respiratorias en zonas de bajos recursos, entregándonos un equipo (espirómetro) accesible para un uso frecuente en zonas de bajos recursos y que cumpla efectivamente con el rol de identificar la patología pulmonar.
## Características del dispositivo
- Sensor de presión diferencial que mide el aire que emite la persona al momento de exhalar.
- Dispositivo buzzer integrado para advertir al paciente cuando esté cometiendo un error en el examen.
- Case impreso en 3D para costos reducidos.
- Portabilidad para una mayor accesibilidad en zonas rurales.
- Bajo consumo de energía.
## Beneficios 
El principal problema que encontramos en la espirometría de bajo costo, es la precisión y la exactitud de los exámenes, debido a que los usuarios no realizan el examen de manera óptima, por lo que la implementación del dispositivo buzzer contribuye en esta situación, generando un sonido luego de realizada la prueba para notificar si es que el usuario a relizado el examen de manera óptima (analizando el tiempo, el flujo de aire y el volumen total del aire inhalado y exhalado del examen realizado por el usuario); dando como consecuencia, un análisis diferenciado.
- Implementación de buzzer (SFM-20B), el cual emitirá distintos tipos de sonido dependiendo de los datos analizados.
- El hardware usado para el ensamble del dispositivo tiene un coste accesible, tomando en cuenta las posibilidades de las zonas de bajos recursos del Perú.
- Su tamaño ayuda a su portabilidad y distribución.
Su bajo consumo energético busca no crear un inconveniente económico a sus usuarios.
El prototipo podrá ser fácilmente replicable al contar con información necesaria para poder ser considerado open hardware.
## Viabilidad técnica
- Uso de dispositivos accesibles como el sensor de presión, microcontrolador, buzzer y una pantalla LCD (MPX210DP, SFM-20B, LCD1622-BMDWH6)
- Conocimiento en softwares de modelado e impresiones en 3D.
- Utilizando el sensor de presión podremos medir el tiempo para el uso correcto del dispositivo.
- Conocimiento en Git.
- Conocimiento en el uso de Arduino.
# Coherencia
## Objetivo general
Desarrollar un espirómetro portátil de bajo costo que permita detectar de manera eficiente un examen realizado correctamente respecto a enfermedades respiratorias como el asma, EPOC y neumonía en zonas de bajos recursos en Perú.
## Objetivos específicos
- Implementar sensores de presión en el espirómetro para medir el flujo de aire del paciente.
- Integrar un microcontrolador para la gestión de los datos obtenidos.
- Diseñar un sistema portátil, accesible y de fácil uso para su implementación en áreas de bajos recursos.
- Validar el prototipo mediante pruebas comparativas con dispositivos comerciales de espirometría.
## Justificación del prototipo
El espirómetro portátil propuesto es la mejor solución debido a su enfoque en reducir costos sin perder su funcionalidad inicial. El dispositivo presenta un sensor de presión diferencial (MPX210DP) con una exactitud del 1%, que mide hasta 10 kPa de presión de trabajo, y tiene un tiempo de respuesta de 1 ms (3). A diferencia de otros dispositivos de mayor precio, este espirómetro utiliza componentes que cumplen con los estándares de diagnóstico a un costo reducido. Mientras que los espirómetros comerciales cuestan aproximadamente 900 soles (4), el costo mínimo estimado de nuestro prototipo es de 200 soles (sensor de presión MPX210DP: 145 soles (5), buzzer SFM-20B: 5 soles (6), pantalla LCD1622-BMDWH6 (7):50  soles sin incluir la carcasa impresa en 3D), lo que lo hace accesible para comunidades vulnerables.

Este espirómetro permite ofrecer un diagnóstico pulmonar preciso a un precio accesible. En las zonas rurales del Perú, donde el acceso a los servicios de salud no es el esperado, un porcentaje significativo de la población no recibe un diagnóstico adecuado. Además, la propuesta mejoraría el acceso al diagnóstico en estas áreas, con componentes que pueden impactar positivamente a las personas en situación de pobreza o vulnerabilidad, quienes actualmente enfrentan graves deficiencias en el diagnóstico temprano de enfermedades respiratorias. Se estima que el dispositivo podría impactar significativamente a esta población, mejorando así la capacidad de diagnóstico en estas zonas.
## Alineación con el problema
Este espirómetro portátil de bajo costo responde a la necesidad de mejorar el diagnóstico de enfermedades respiratorias (asma, EPOC, neumonía) en zonas de bajos recursos en Perú, donde el acceso a equipos médicos avanzados es limitado. Actualmente, los espirómetros comerciales son costosos y requieren infraestructura y personal especializado, lo que los hace poco accesibles para estas comunidades.

El 20% de la población peruana vive en zonas rurales, donde el acceso a servicios de salud es deficiente. Dentro de este grupo, el 40% es pobre y otro 40% es vulnerable, enfrentando dificultades en el acceso a diagnósticos tempranos de enfermedades respiratorias como el asma, la EPOC y la neumonía (8). En las áreas rurales, solo el 3,1% de la población adulta mayor ha sido diagnosticada con asma, en comparación con el 4,9% en áreas urbanas. Además, la neumonía ha causado 248 defunciones en menores de 5 años, siendo Loreto, Cusco y Junín los departamentos con mayor número de casos (9). 

La solución propuesta, basada en un sensor de presión diferencial y un microcontrolador, ofrece una alternativa accesible y fácil de usar, que puede implementarse en áreas rurales. Esto permitirá realizar diagnósticos tempranos y mejorar el manejo de enfermedades respiratorias, reduciendo la brecha de atención médica en poblaciones vulnerables.

# Resumen
La accesibilidad al diagnóstico y seguimiento de enfermedades pulmonares ha sido y sigue siendo una problemática en las zonas alejadas del mundo donde los servicios de salud son precarios. Pruebas como la espirometría han tenido avances en su accesibilidad a este tipo de poblaciones, pero siguen habiendo retos que deben ser enfrentados, como la baja precisión y exactitud, necesidad de especialistas, el cansancio que genera debido a la repetición, etc. Es por esto que nuestra solución se enfoca en la accesibilidad en costo y portabilidad, y en generar avisos al paciente para notificarle sobre un proceso de expiración erróneo que pueda afectar a los resultados de la prueba.

Nuestra visión para el dispositivo es que con este se puedan realizar campañas y visitas a hogares de poblaciones vulnerables que vivan en zonas alejadas para que no se den casos de enfermedades pulmonares no diagnosticadas, las cuales en casos graves, pueden llevar al paciente a la muerte.

Nuestro siguiente paso para hacer realidad el proyecto a partir de lo que tenemos, es especificar aquellas características que queremos implementar, buscar componentes que se puedan integrar unos con otros y que sean de un buen costo para nuestro propósito de brindar accesibilidad. 

# Fuentes 

[1]	Centro Nacional de Epidemiología, Prevención y Control de Enfermedades, “BOLETÍN EPIDEMIOLÓGICO DEL PERÚ”, 2023.

[2]	S. P. de Neumología, “Guía Peruana de EPOC - 2016”, 2016.

[3] Mouser.pe. [En línea]. Disponible en: https://www.mouser.pe/ProductDetail/NXP-Semiconductors/MPX2010DP?qs=N2XN0KY4UWUZAyVjnqwQiQ%3D%3D. 

[4] “Espirómetro digital”, Medifay |, 16-feb-2021. [En línea]. Disponible en: https://www.medifay.pe/producto/espirometro-digital/.

[5] “Sensor de Presión MPX2010DP”, Electromanía Perú. [En línea]. Disponible en: https://www.electromania.pe/producto/sensor-de-presion-mpx2010dp/. 

[6] Naylampmechatronics.com. [En línea]. Disponible en: https://naylampmechatronics.com/interfaz-de-usuario/367-piezo-buzzer-activo-sfm-20b-dc3-24v-2312.html.

[7] Naylampmechatronics.com. [En línea]. Disponible en: https://naylampmechatronics.com/lcd-alfanumerico/653-display-alfanumerico-lcd-lc1622-verde.html.

[8] “La deficiente atención de salud en área rural”, ArchivoRevista Ideele. [En línea]. Disponible en: https://revistaideele.com/ideele/content/la-deficiente-atenci%C3%B3n-de-salud-en-%C3%A1rea-rural.

[9] Gob.pe. [En línea]. Disponible en: https://www.inei.gob.pe/media/MenuRecursivo/publicaciones_digitales/Est/Lib1146/cap04.pdf.

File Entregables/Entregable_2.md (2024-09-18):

# Estado de arte
## Contec SP10BT
El espirómetro Contec SP 10 BT es una herramienta de diagnóstico no invasiva que emplea infrarrojos para evaluar la función pulmonar. Ofrece una amplia gama de mediciones, incluyendo FVC, FEV1, PEF y flujos espiratorios a diferentes porcentajes del FVC. Además, presenta gráficos de flujo-volumen y volumen-tiempo, almacenamiento de datos y función de calibración. Su diseño portátil y fácil uso lo hacen ideal para evaluaciones rutinarias en diversos entornos clínicos. Precio: 900 soles.

SP10BT
## Contec SP70B
El Contec SP70B es un espirómetro portátil que evalúa la salud pulmonar de manera fácil y rápida. Utiliza tecnología infrarroja para medir diversos parámetros respiratorios como FVC, FEV1 y PEF. Permite personalizar los resultados según las características del usuario y almacenar hasta 9999 registros. Además, cuenta con conexión Bluetooth para transferir datos y una batería de larga duración. Es ideal para uso clínico y doméstico. Precio: 720 soles.

SP70B
## Contec SP90
El Espirómetro Contec SP90 es un dispositivo portátil de alta precisión diseñado para evaluar la función pulmonar en diversos entornos clínicos. Utilizando un avanzado sensor de presión diferencial, este espirómetro ofrece resultados precisos y una respuesta rápida, ideal para el diagnóstico y la evaluación terapéutica de enfermedades respiratorias como el asma, EPOC, y fibrosis pulmonar. Su diseño compacto y ligero, junto con una pantalla TFT HD y funcionalidades de conectividad avanzadas, hacen del SP90 una herramienta esencial en medicina respiratoria, anestesiología, y más. Precio: 1700

SP90
## Contexto comercial

## Patentes de Invención
### Sistema de diagnóstico de espirometría portátil personal
- **Número de patente:** [KR1020220167645](https://patentscope.wipo.int/search/es/detail.jsf?docId=KR383841388&_cid=P12-M14AZK-98835-1) (1)
- **Año:** 2022
- **País:** Corea del Sur

<div style="display: flex; align-items: center;">
  description
  <p>La patente describe un "Sistema de Diagnóstico de Espirometría Personal y Portátil". Este dispositivo está diseñado para ofrecer pruebas de espirometría de manera compacta y portátil, permitiendo a los usuarios evaluar su función pulmonar en cualquier lugar. Sus características incluyen un diseño ergonómico para facilitar el uso en el hogar o en movimiento, sensores precisos para medir el flujo y volumen de aire, y la capacidad de almacenar y analizar datos para el diagnóstico de afecciones respiratorias como el asma o la enfermedad pulmonar obstructiva crónica (EPOC). La importancia de esta patente radica en su capacidad para proporcionar una herramienta de diagnóstico accesible y conveniente, lo que puede mejorar la gestión de enfermedades respiratorias y permitir un monitoreo más frecuente y personalizado de la salud pulmonar.</p>
</div>

### Métodos de espirometría para diagnosticar la destrucción leve y temprana del flujo aéreo
- **Número de patente:** [WO2022036172](https://patentscope.wipo.int/search/es/detail.jsf?docId=WO2022036172&_cid=P12-M14B1X-01074-1) (2)
- **Año:** 2022
- **País:** Estados Unidos

<div style="display: flex; align-items: center;">
  description
  <p>Esta patente se enfoca en métodos avanzados para diagnosticar obstrucción leve y temprana del flujo aéreo mediante espirometría. Las especificaciones incluyen técnicas mejoradas para medir parámetros como la velocidad máxima de flujo espiratorio (PEF) y el flujo expiratorio forzado en 1 segundo (FEV1). Utiliza algoritmos avanzados para analizar estos datos y detectar patrones sutiles que indican obstrucción antes de que sea evidente con métodos convencionales. Además, incorpora sensores de alta precisión y dispositivos de espirometría que permiten una recolección de datos más detallada y fiable, facilitando una intervención temprana en enfermedades respiratorias como el asma y la EPOC.</p>
</div>

## Patente de Modelo de Utilidad
### Método y dispositivo para mediciones respiratorias utilizando muestras de gas de respiración
- **Número de patente:** [US20220110541A1](https://patents.google.com/patent/US20220110541A1/en?oq=ES2843105T3) (3)
- **Año:** 2021
- **País:** España

La patente describe un dispositivo y método para medir la eficacia del intercambio de gases en los pulmones de manera no invasiva, utilizando muestras de gas respiratorio. El sistema mide la presión parcial de oxígeno (O2) y dióxido de carbono (CO2) durante la respiración y calcula indicadores como la saturación de oxígeno en sangre y el cociente respiratorio.

**Características relevantes:**
- Medición no invasiva: Evalúa la función respiratoria sin necesidad de extraer sangre.
- Detección y monitoreo: Puede detectar condiciones respiratorias anómalas, como hipoxemia y EPOC.
- Multifuncionalidad: Integra sensores para monitorear varios parámetros respiratorios, permitiendo su uso en diferentes pruebas respiratorias.
- Visualización y Alarma: Incluye una pantalla para mostrar los resultados y un sistema de alarmas para alertar sobre problemas respiratorios.
<div style="text-align: center;">
  description
</div>
<br>

# Requerimientos del proyecto
<div style="text-align: center;">
  <table border="1" style="width:100%; margin-left:auto; margin-right:auto;">
    <tr>
      <th style="width:50%">No funcionales</th>
      <th style="width:50%">Funcionales</th>
    </tr>
    <tr>
      <td>Portabilidad. Característica necesaria para el uso en zonas de difícil acceso, una buena portabilidad hará posible el uso del dispositivo en más lugares.</td>
      <td>Medir el flujo y volumen de aire del paciente haciendo uso de sensores.</td>
    </tr>
     <tr>
      <td>Interfaz amigable. Al momento de crear de herramienta de salud accesible, el entorno con el que interactúa el usuario debe ser familiar para él.</td>
      <td>Gestionar los datos de los sensores haciendo uso de un microcontrolador.</td>
    </tr>
    <tr>
      <td>Replicabilidad. Propiedad indispensable para cualquier proyecto open hardware.</td>
      <td>Diferenciación de patologías según las gráficas de resultados.</td>
    </tr>
    <tr>
      <td>No invasivo. A miras de crear un dispositivo simple, un enfoque no invasivo es el más ideal nos permite desarrollar un dispositivo con menor riesgo.</td>
      <td>Evaluación del paciente para determinar su capacidad pulmonar y riesgo a enfermedades pulmonares.</td>
    </tr>
    <tr>
      <td>Bajo costo. Nuestro enfoque en zonas de bajos ingresos requiere de un dispositivo accesible económicamente.</td>
      <td> </td>
    </tr>
   
  </table>
</div>

# Propuesta de solución
<h3>Espirómetro portable de bajo costo que facilite la diferenciación de las principales enfermedades pulmonares (asma, EPOC, neumonía) haciendo uso de sensores de presión y un microcontrolador para la gestión de datos.</h3>

# Fuentes bibliográficas

- (1) 개인용 휴대형 폐활량 진단 시스템. 2022. PERSONAL PORTABLE SPIROMETRY DIAGNOSIS SYSTEM. (Patent No. KO:KR1020220167645). In KO Patent (No. KR1020220167645)

- (2) MÉTHODES DE SPIROMÉTRIE POUR DIAGNOSTIC D'UNE OBSTRUCTION DES VOIES RESPIRATOIRES MODÉRÉE ET PRÉCOCE. 2021. SPIROMETRY METHODS TO DIAGNOSE MILD AND EARLY AIRFLOW OBSTRUCTION. (Patent No. FR:WO2022036172). In FR Patent (No. WO2022036172)

- (3) Methods Of Non-Invasively Determining Blood Oxygen Level And Related Pulmonary Gas Exchange Information. 2021. (Patent No. US:US20220110541A1). In US Patent (No. US20220110541A1).

- (4) https://www.contecmed.com/

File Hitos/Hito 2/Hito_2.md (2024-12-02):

# Lungie
## Problemática
La falta de servicios de salud competentes en el Perú ha causado problemas en todo el país, pero las zonas que más afectadas se han visto han sido aquellas con menos recursos.
Esta deficiencia en el servicio de salud se debe a varios motivos, entre ellos la falta de dispositivos de diagnóstico eficientes y de bajo costo lo que ocasiona que veamos cifras tan alarmantes como llegar a ver aproximadamente un 64% de diagnósticos erróneos en el país [1, 2].
## Solución
Es por esto que hemos desarrollado un espirómetro de bajo costo accesible para estas zonas de bajos recursos del país.
La espirometría es una técnica de detección de enfermedades respiratorias obstructivas la cual permite el diagnóstico de las mismas. 

Nuestro proyecto busca ser principalmente un dispositivo portable, de bajo costo, y con una interfaz amigable.
Funciona en tres simples pasos:
1. El paciente exhala a través de la boquilla del espirómetro.
2. Los datos son registrados y procesados por el dispositivo.
3. Se obtienen los resultados y valores buscados.
## Desarrollo del proyecto
### Boceto inicial
Al inicio del proyecto planteamos un boceto que nos sirvió de guía durante el resto del desarrollo.
Como podrán ver a continuación, este borrador inicial se asemeja mucho a como terminó nuestro prototipo actual.
boceto
### Modelado 3D
El siguiente paso en nuestro objetivo fue realizar el modelado 3D.
Gracias al software OneShape y las librerías de GrabCad pudimos realizar nuestro modelado 3D, el cual después de pasar diversas revisiones por parte de los docentes, recibió el visto bueno y fue mandado a imprimir.
- Vista isométrica sin la tapa:
sin_tapa
- Vista isométrica con la tapa:
con_tapa
### Manufactura digital
Nuestro proyecto únicamente necesitaba de impresión 3D, ya que lo único necesario era una carcasa y soportes para los componentes.
Al recibir nuestra primera impresión, nos dimos cuenta de errores respecto a las dimensiones de los soportes y huecos para tornillos, los cuales se encontraban desfasados.
Tomando nota de estos errores, hicimos los cambios en el modelado y volvimos a imprimir una segunda versión de la carcasa, la cual finalmente pudo complementarse correctamente con los componentes.
- Borrador inicial
primera_impresión
### Diagrama de flujo
Haciendo uso de las librerías correspondientes y las ecuaciones físicas para el cambio de voltaje a flujo hicimos nuestro diagrama de flujo final a partir del cual escribimos nuestro [borrador final del código](https://github.com/leomachiavello/FundBio2024-2/blob/main/Software/borradores/borrador6/borrador6.ino).
diagrama
### Esquema electrónico
A diferencia de nuestro esquema electrónico del [Hito 1](https://github.com/leomachiavello/FundBio2024-2/blob/main/Hitos/Hito_1.md), en este prototipo hemos eliminado el regulador de voltaje, ya que ninguno de nuestros componentes lo necesitaba.
También hemos agregado una segunda etapa de amplificación de la señal del sensor de presión haciendo uso de un segundo amplificador LM348.
esquema
### Limitaciones
A lo largo de nuestro desarrollo del proyecto nos encontramos con varios percances que limitaron el óptimo funcionamiento del prototipo según nuestro planteamiento. Entre los principales podemos encontrar:
- **Mala compatibilidad entre las librerías de la pantalla OLED (Adafruit) y del lector SD (SD.h):** Cuando usábamos ambas librerías en el mismo programa ninguno de los componentes funcionaba, por lo que tuvimos que recurrir a cambiar de biblioteca de la pantalla OLED a SSD1306 Ascii que es más ligera, por lo que permite el uso de ambas a la vez. Esta librería tiene la desventaja de tener menos opciones, pero aún así se pudo usar para nuestro propósito, ya que solo nos interesa mostrar texto en nuestra pantalla.
- **Amplificadores:** Ambos amplificadores, el de instrumentación (INA126) y el secundario (LM348) nos han dado bastantes problemas durante el desarrollo del proyecto. El INA126 presentaba una gran cantidad de ruido de señal que no permitía una correcta toma de datos del espirómetro, mientras que el LM348 necesitaba de más voltaje del que es capaz nuestro microcontrolador. 
## Referencias
[1] S. P. de Neumología, “Guía Peruana de EPOC - 2016”, 2016.

[2] Centro Nacional de Epidemiología, Prevención y Control de Enfermedades, “BOLETÍN EPIDEMIOLÓGICO DEL PERÚ”, 2023.

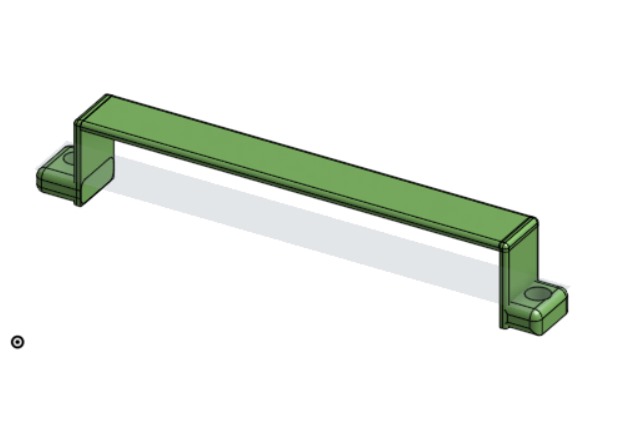
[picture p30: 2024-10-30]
Hardware/Diseño mecánico/Renders/Piezas/soporte_largo.jpeg

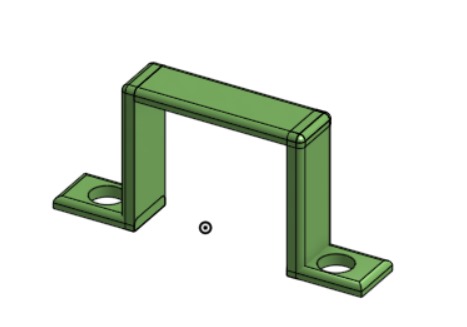
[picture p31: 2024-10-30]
Hardware/Diseño mecánico/Renders/Piezas/soporte_corto.jpeg

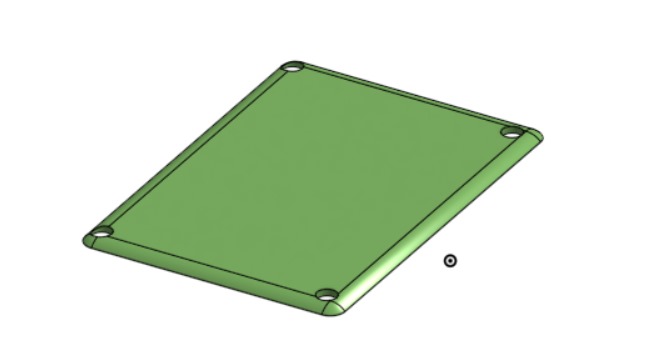
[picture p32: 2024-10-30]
Hardware/Diseño mecánico/Renders/Piezas/tapa_2.jpeg

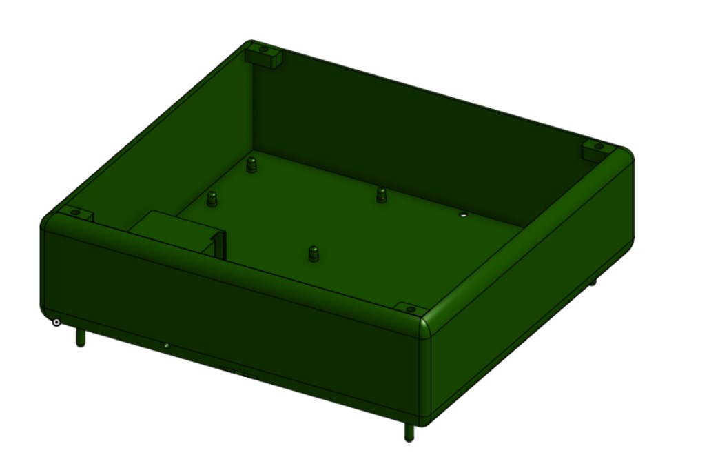
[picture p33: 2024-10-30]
Hardware/Diseño mecánico/Renders/Piezas/base.jpeg

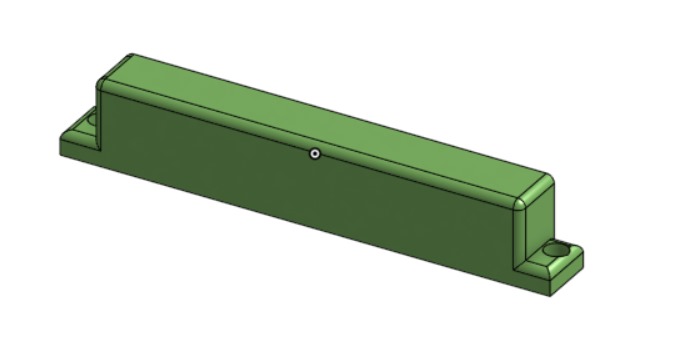
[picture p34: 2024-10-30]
Hardware/Diseño mecánico/Renders/Piezas/soporte_3.jpeg

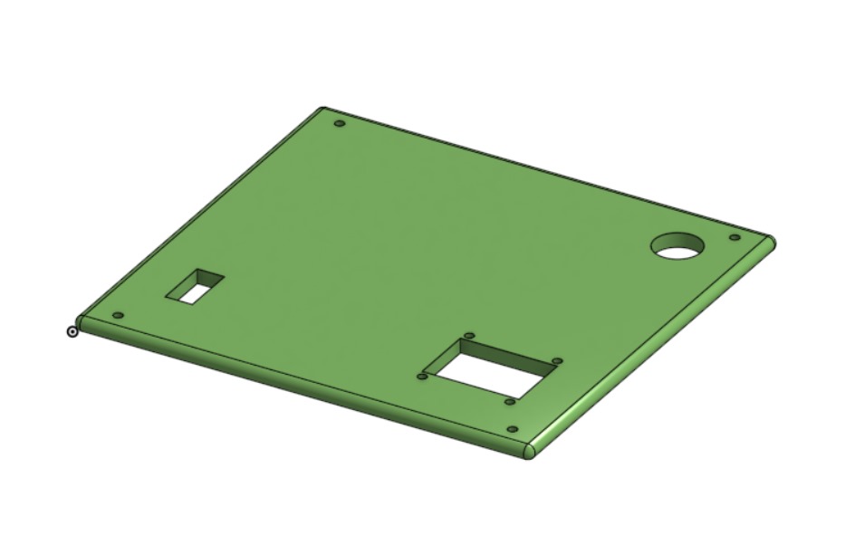
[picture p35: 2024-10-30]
Hardware/Diseño mecánico/Renders/Piezas/tapa.jpeg

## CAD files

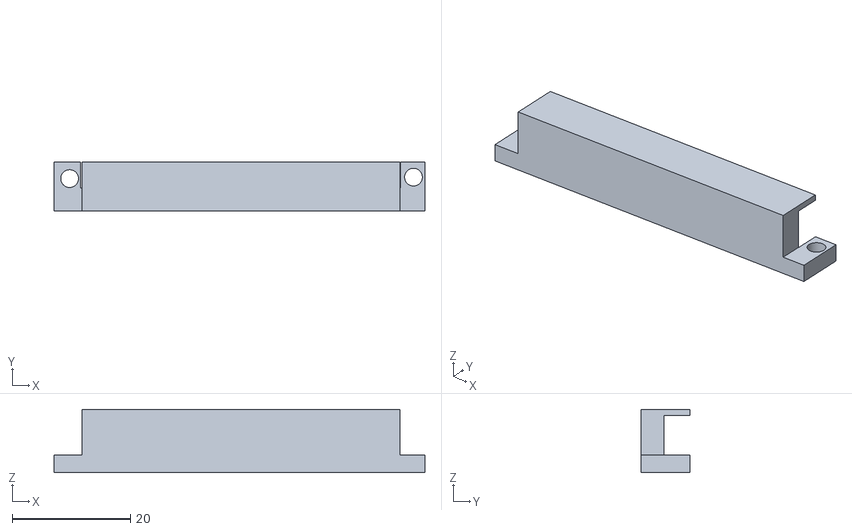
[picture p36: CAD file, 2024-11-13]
Hardware/Diseño mecánico/Archivos STL/Soporte Protoboard.stl
62.7 x 8.34 x 10.7

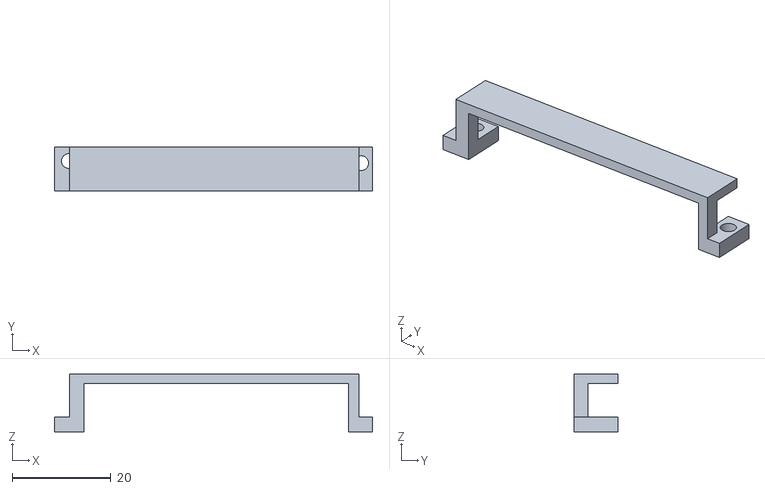
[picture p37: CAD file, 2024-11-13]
Hardware/Diseño mecánico/Archivos STL/Sorporte Protoboard Pared.stl
64.5 x 8.82 x 11.7

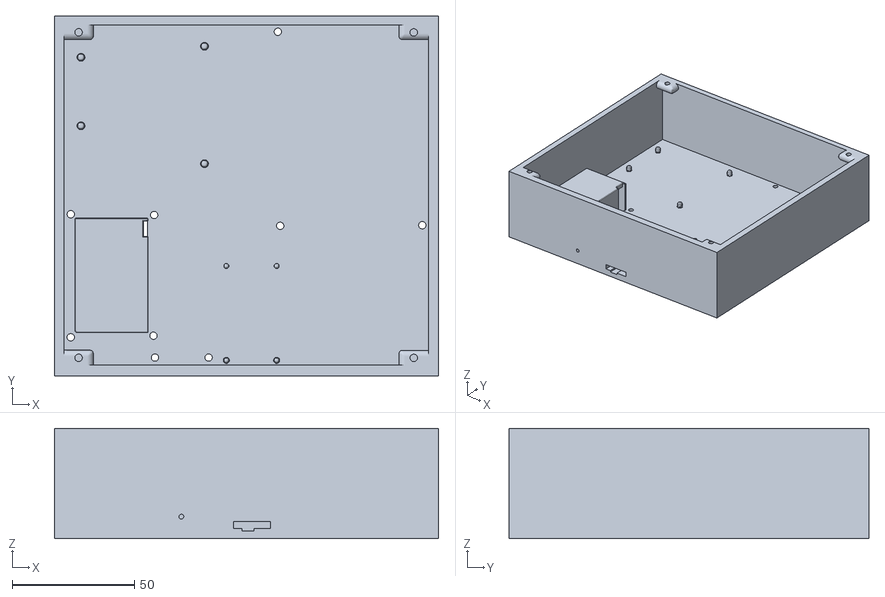
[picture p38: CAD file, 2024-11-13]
Hardware/Diseño mecánico/Archivos STL/Base.stl
157.0 x 147.0 x 45.0

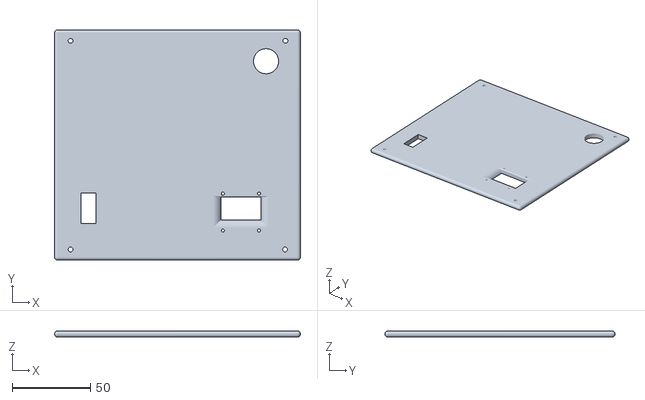
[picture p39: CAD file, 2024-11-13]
Hardware/Diseño mecánico/Archivos STL/Tapa.stl
157.0 x 147.0 x 4.00

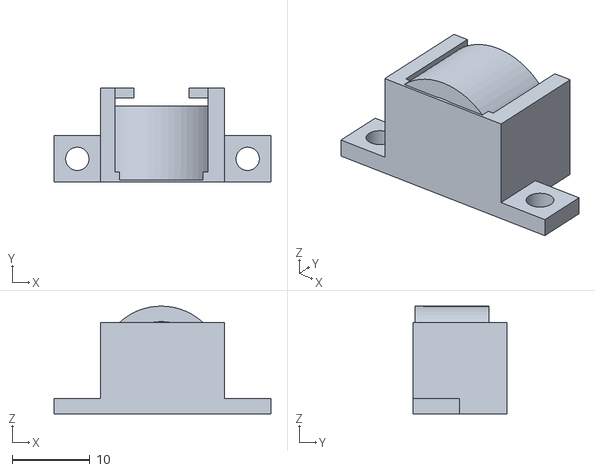
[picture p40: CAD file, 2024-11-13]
Hardware/Diseño mecánico/Archivos STL/Soporte Buzzer.stl
27.9 x 12.1 x 13.9

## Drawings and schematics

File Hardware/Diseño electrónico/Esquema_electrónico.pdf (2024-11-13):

## Lector de memoria Micro SD Card 74LVC125A Buzzer tonal TMB12A05 Sensor de presion MPX2010DP

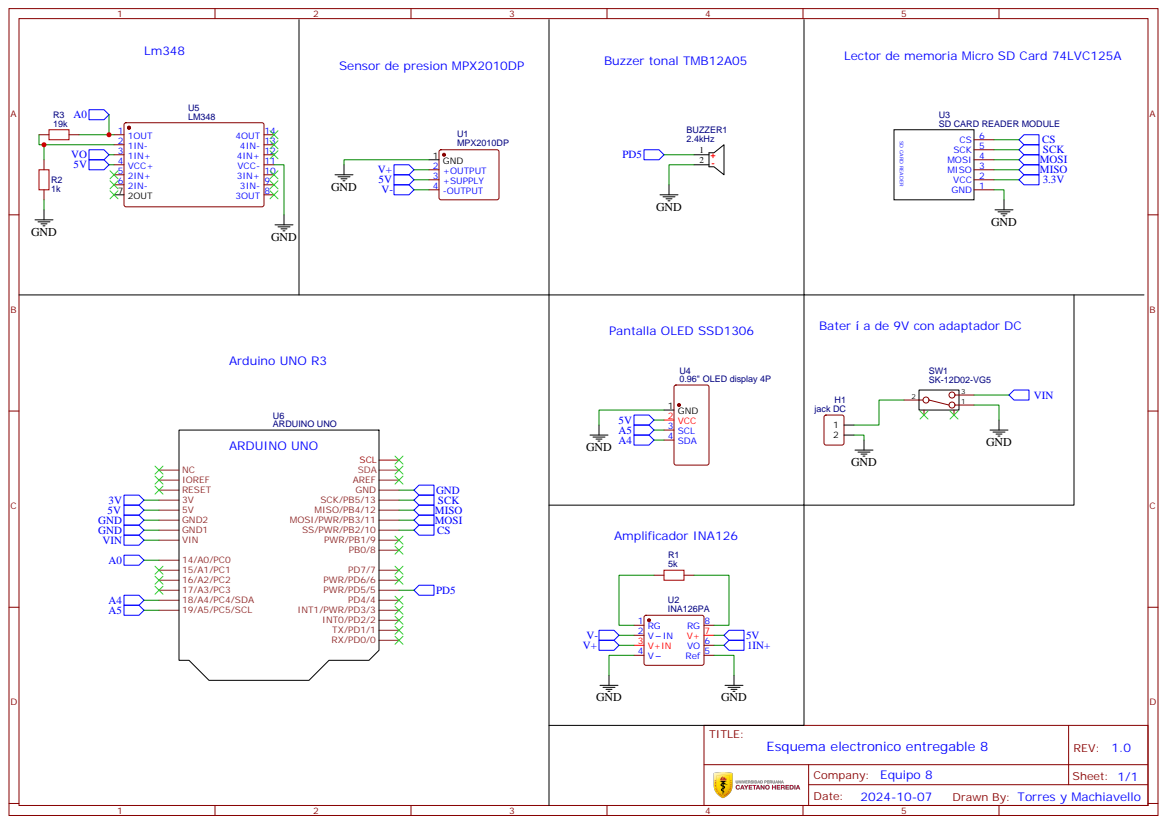
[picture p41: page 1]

Drawn By: Torres y Machiavello

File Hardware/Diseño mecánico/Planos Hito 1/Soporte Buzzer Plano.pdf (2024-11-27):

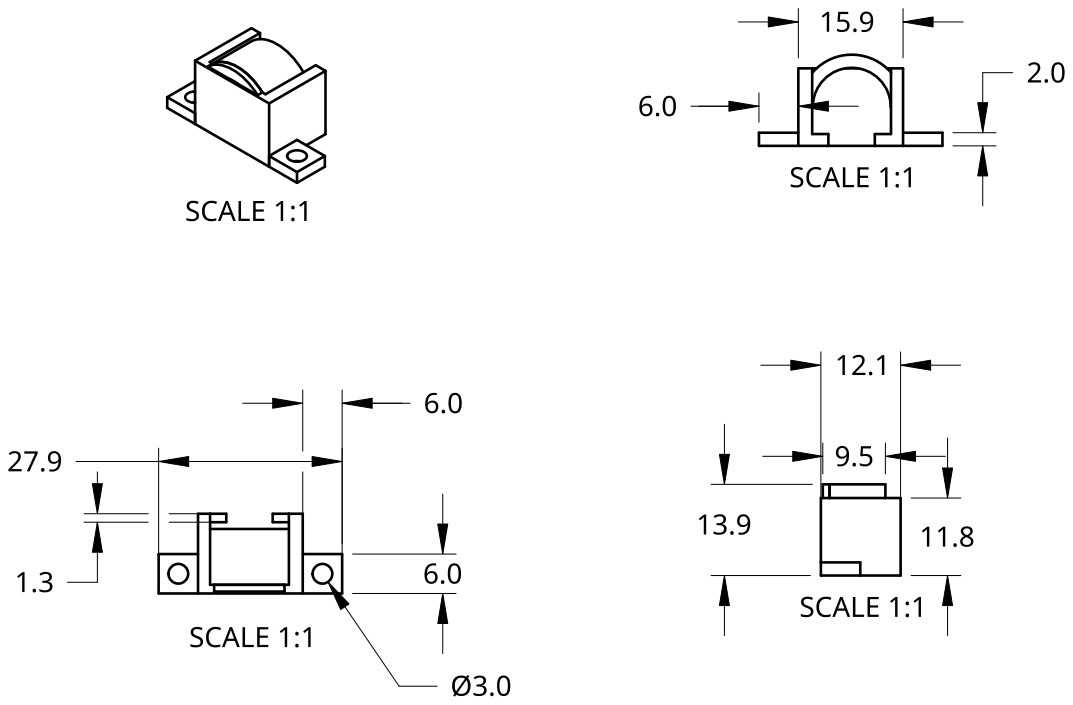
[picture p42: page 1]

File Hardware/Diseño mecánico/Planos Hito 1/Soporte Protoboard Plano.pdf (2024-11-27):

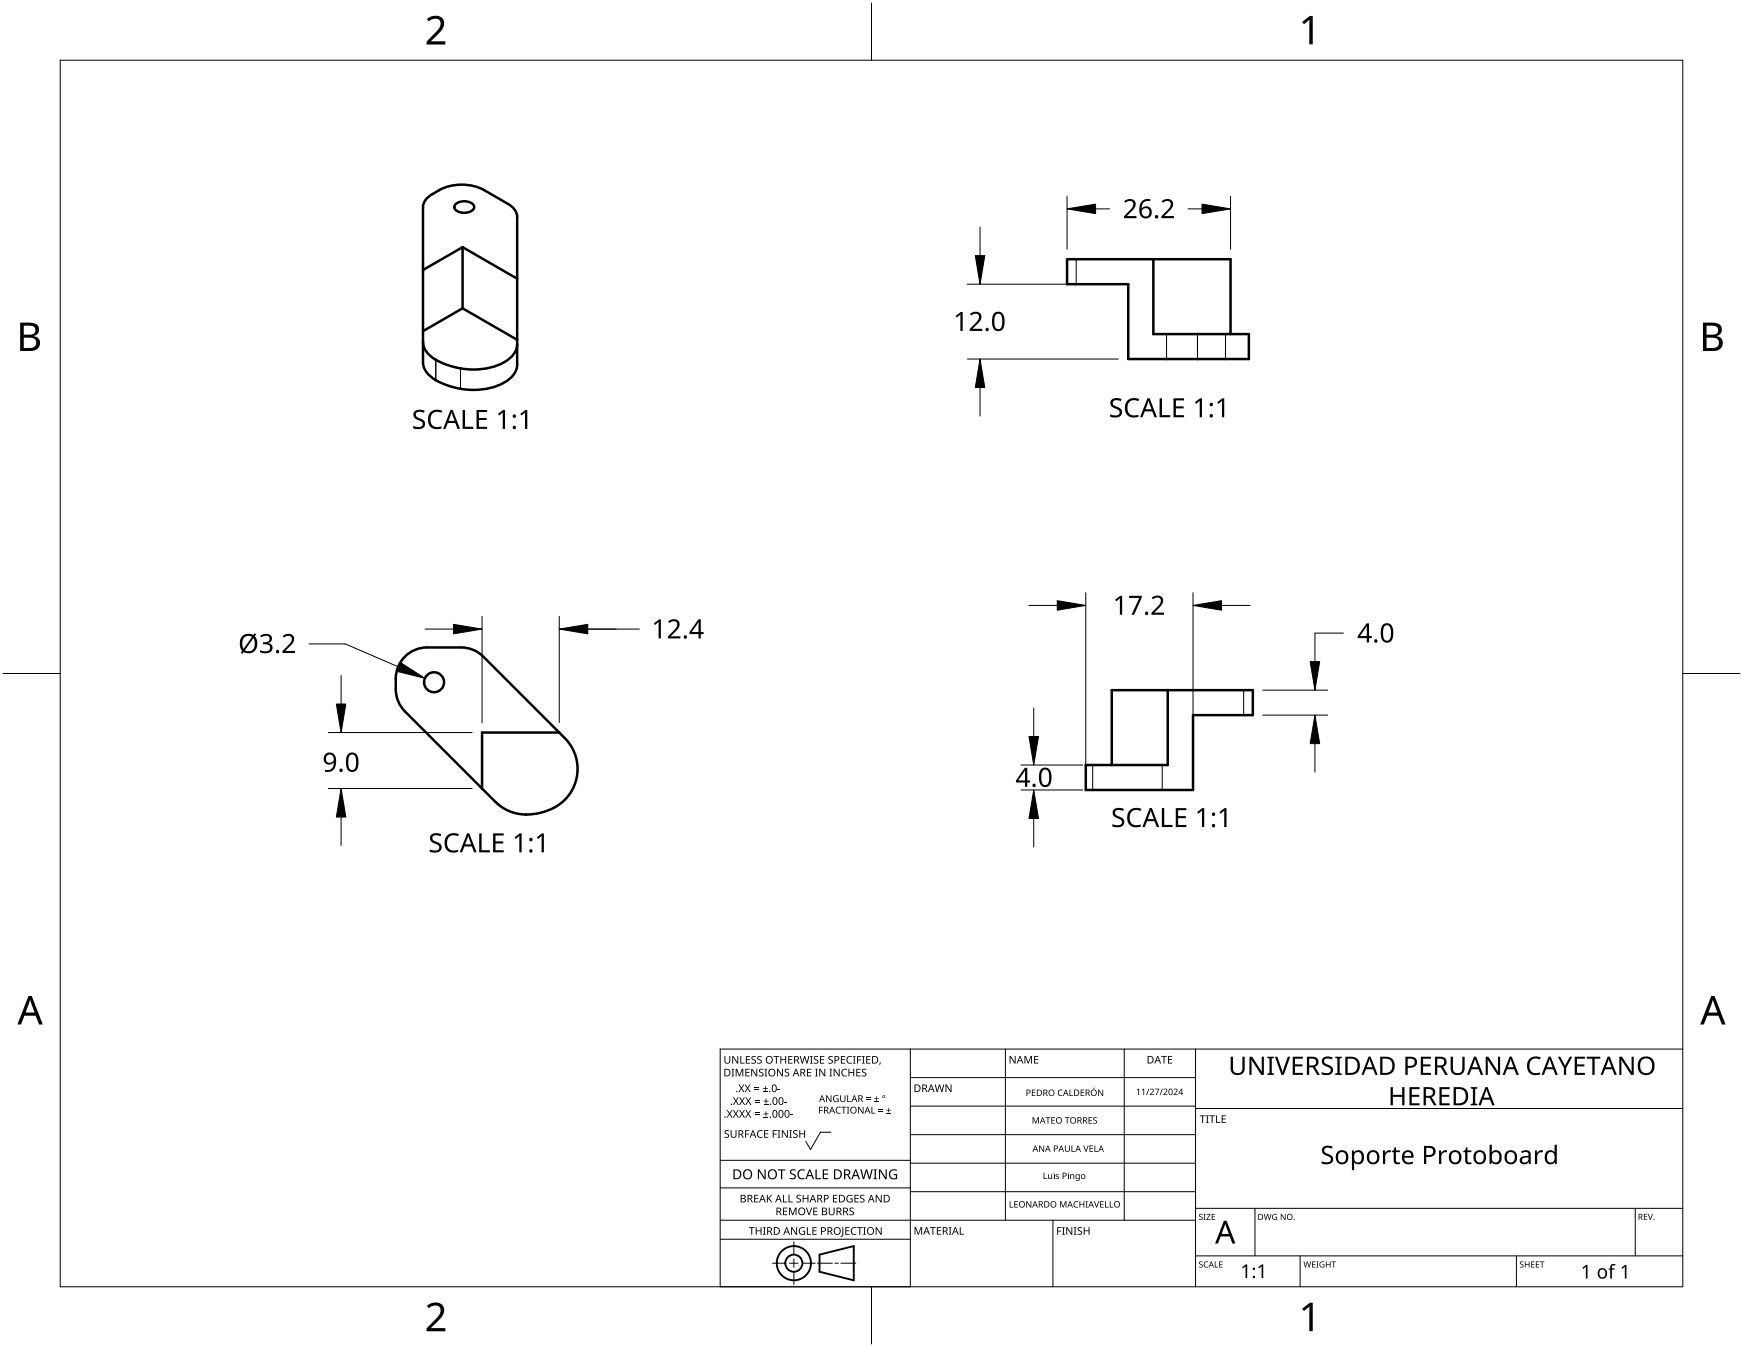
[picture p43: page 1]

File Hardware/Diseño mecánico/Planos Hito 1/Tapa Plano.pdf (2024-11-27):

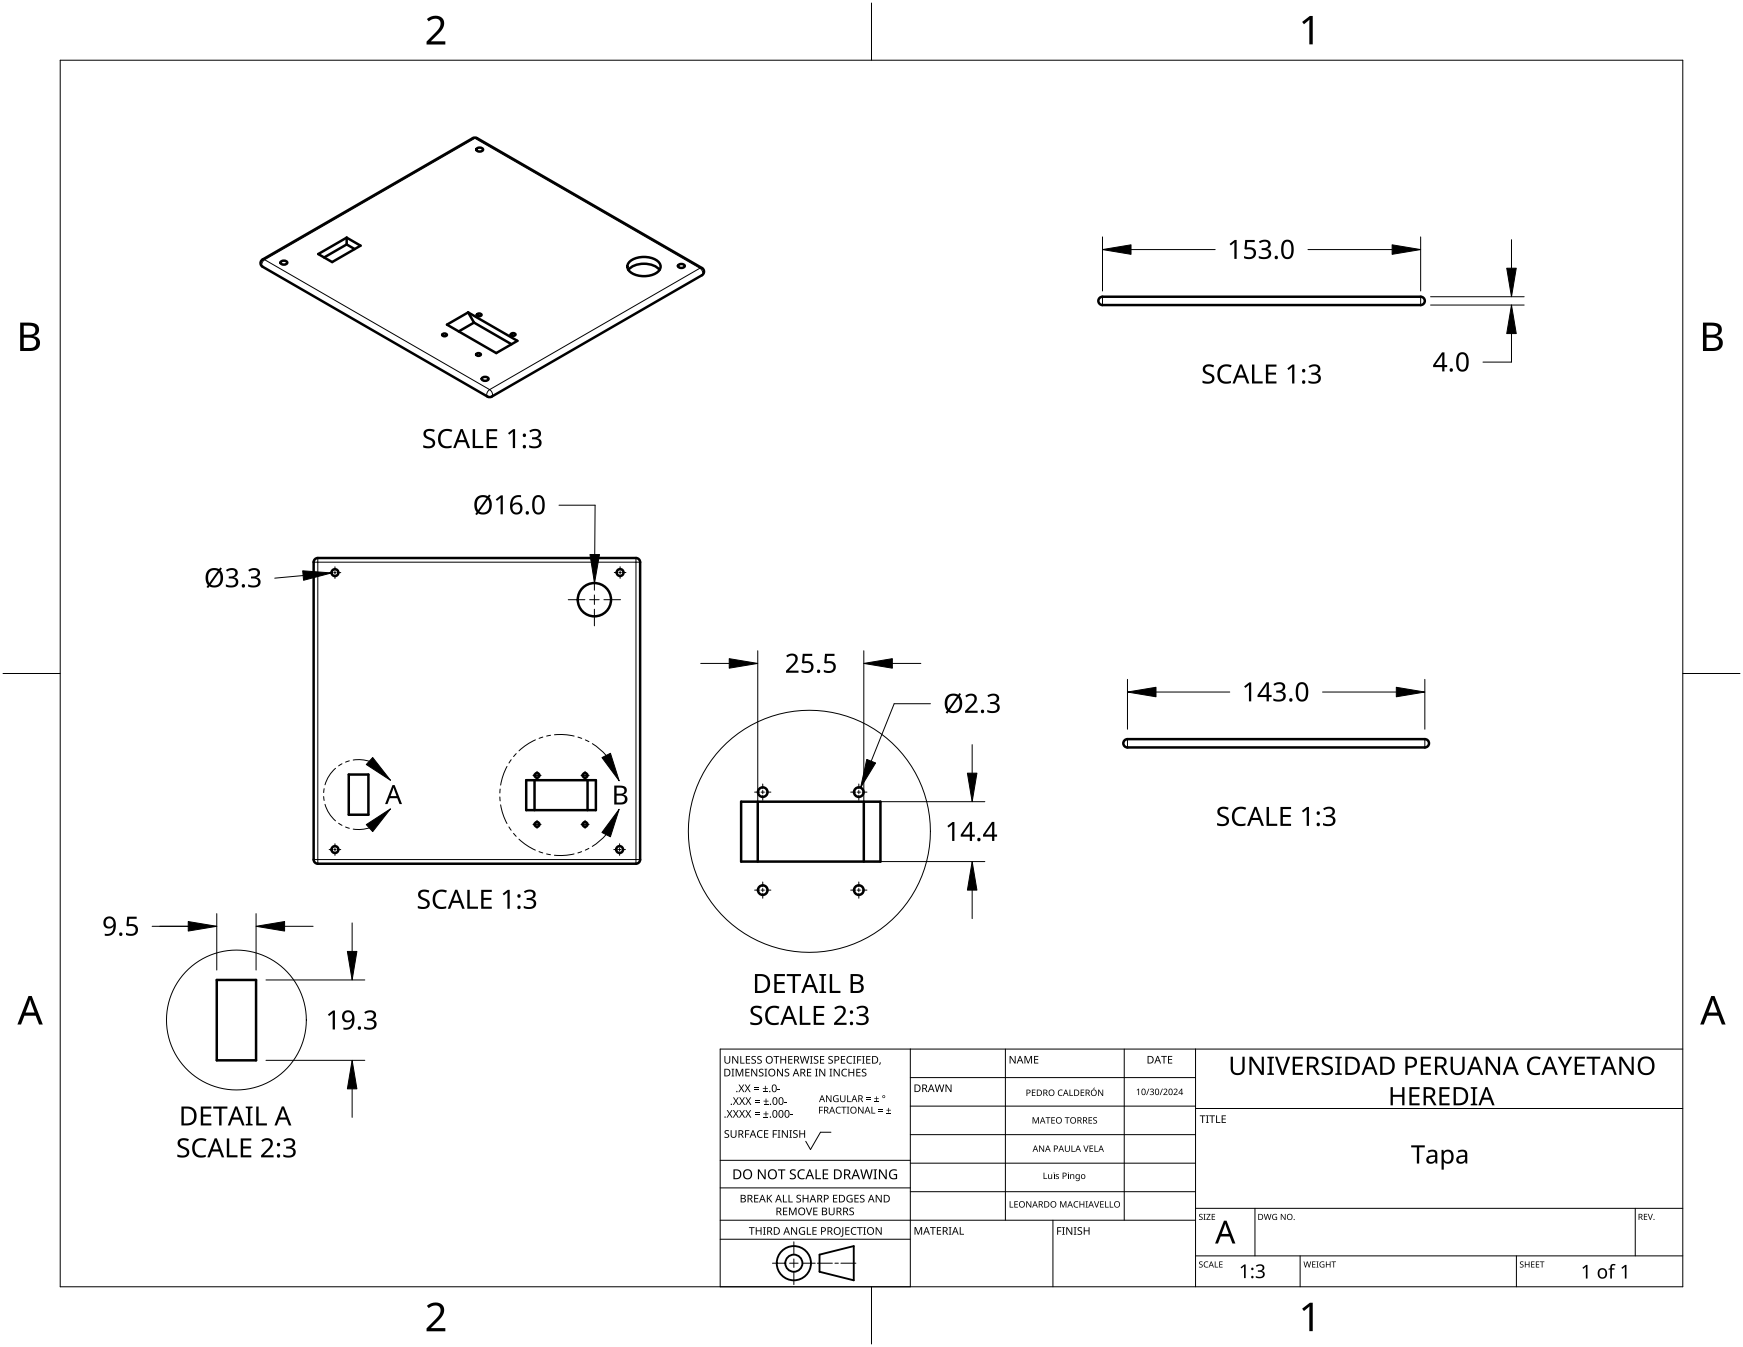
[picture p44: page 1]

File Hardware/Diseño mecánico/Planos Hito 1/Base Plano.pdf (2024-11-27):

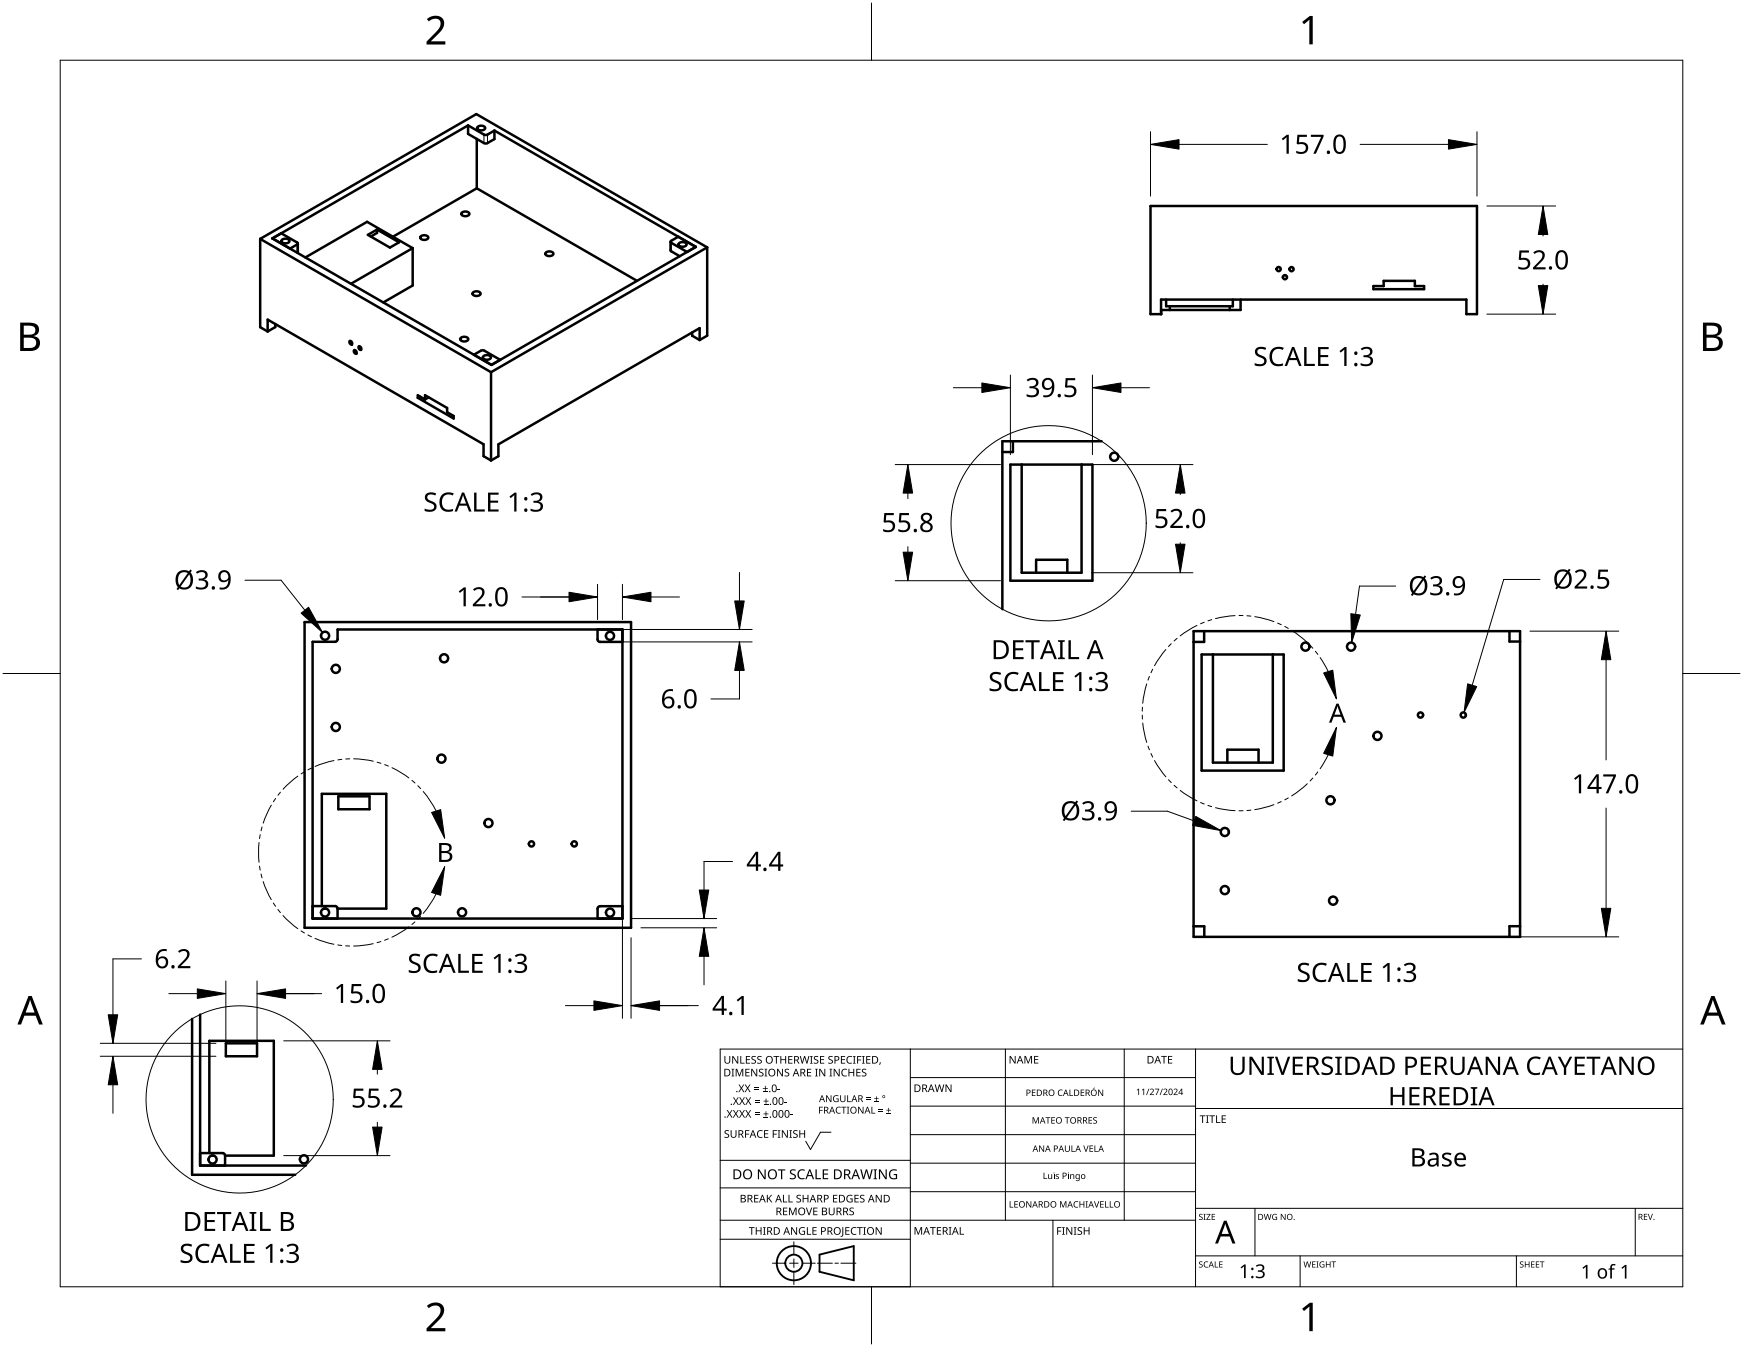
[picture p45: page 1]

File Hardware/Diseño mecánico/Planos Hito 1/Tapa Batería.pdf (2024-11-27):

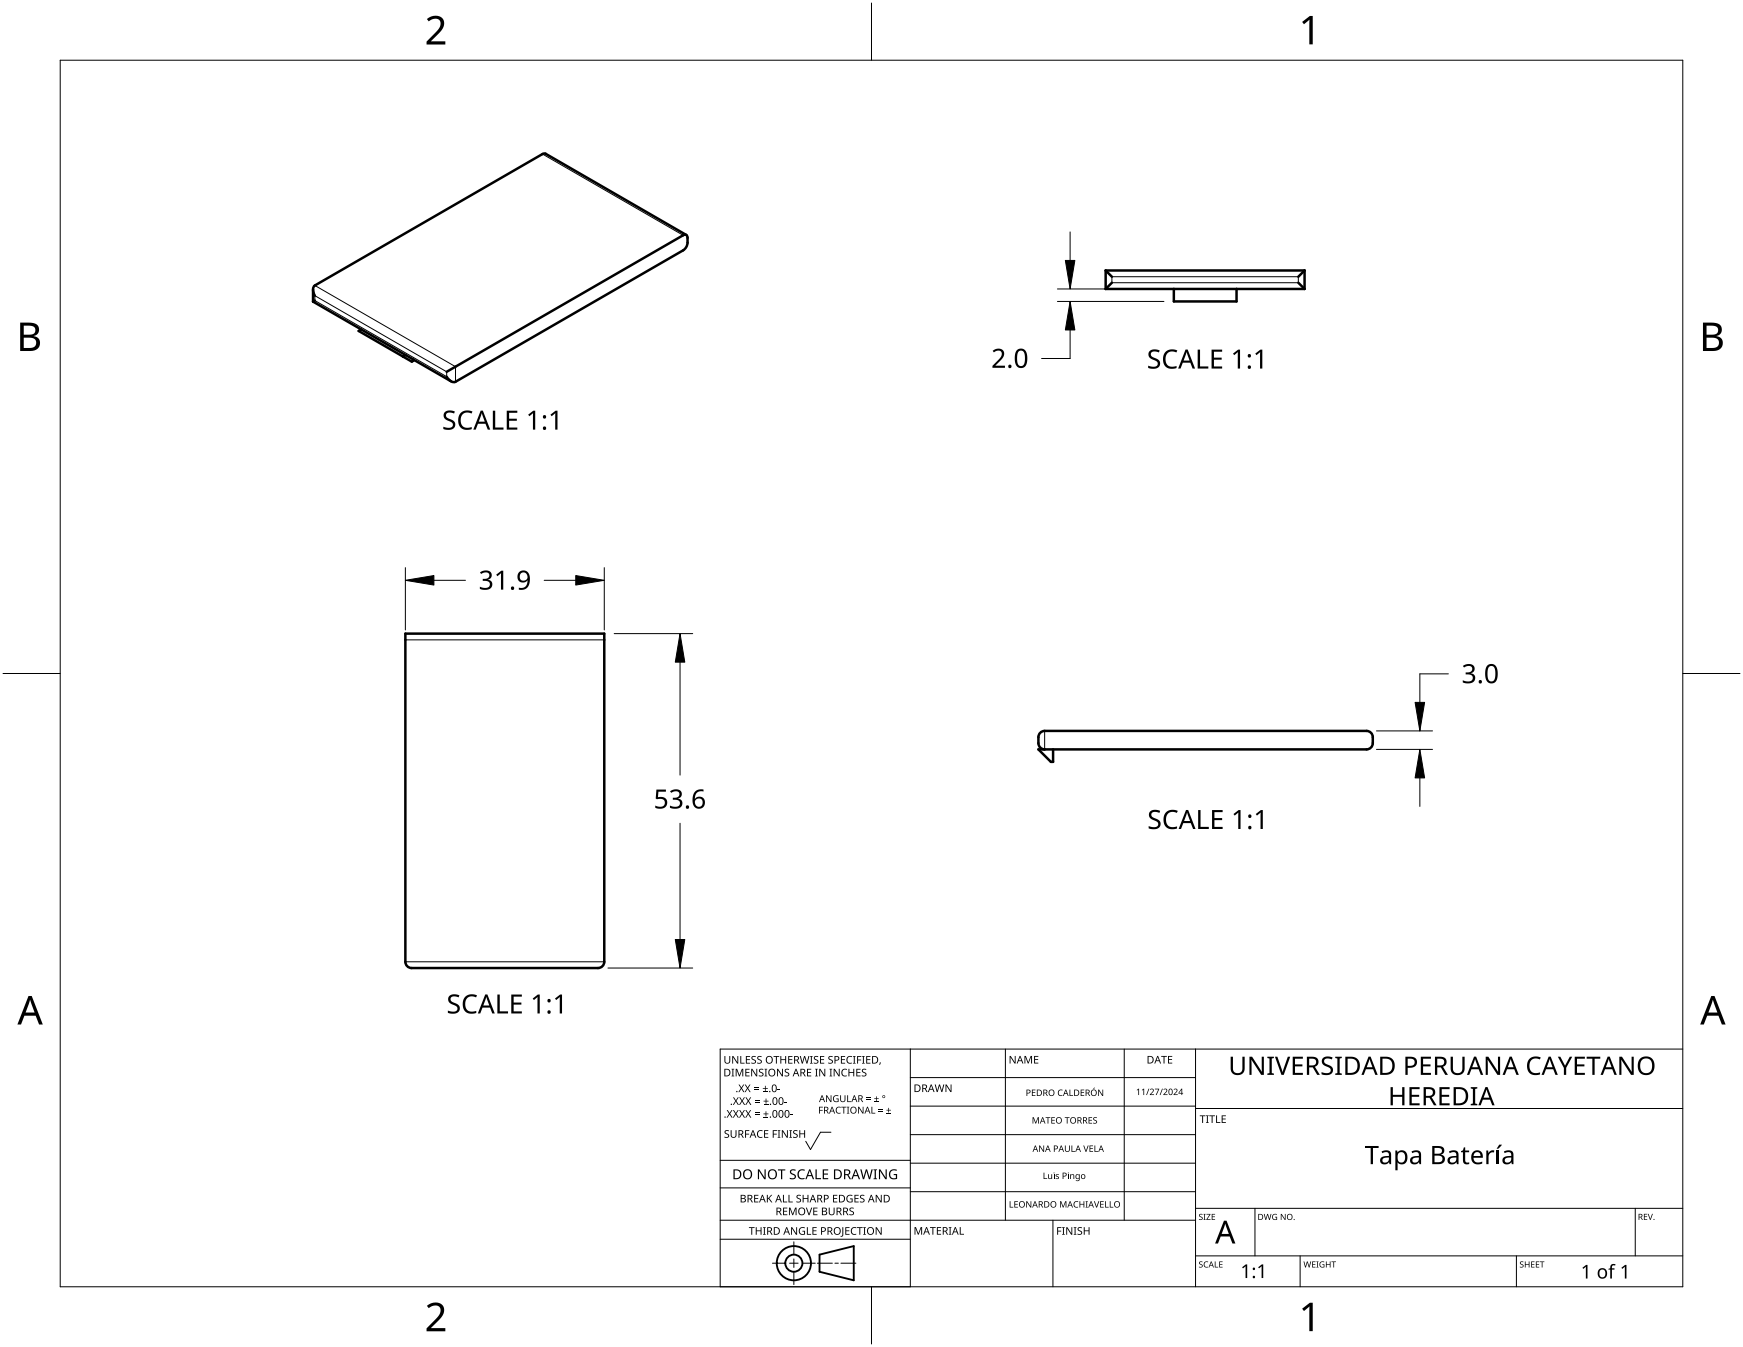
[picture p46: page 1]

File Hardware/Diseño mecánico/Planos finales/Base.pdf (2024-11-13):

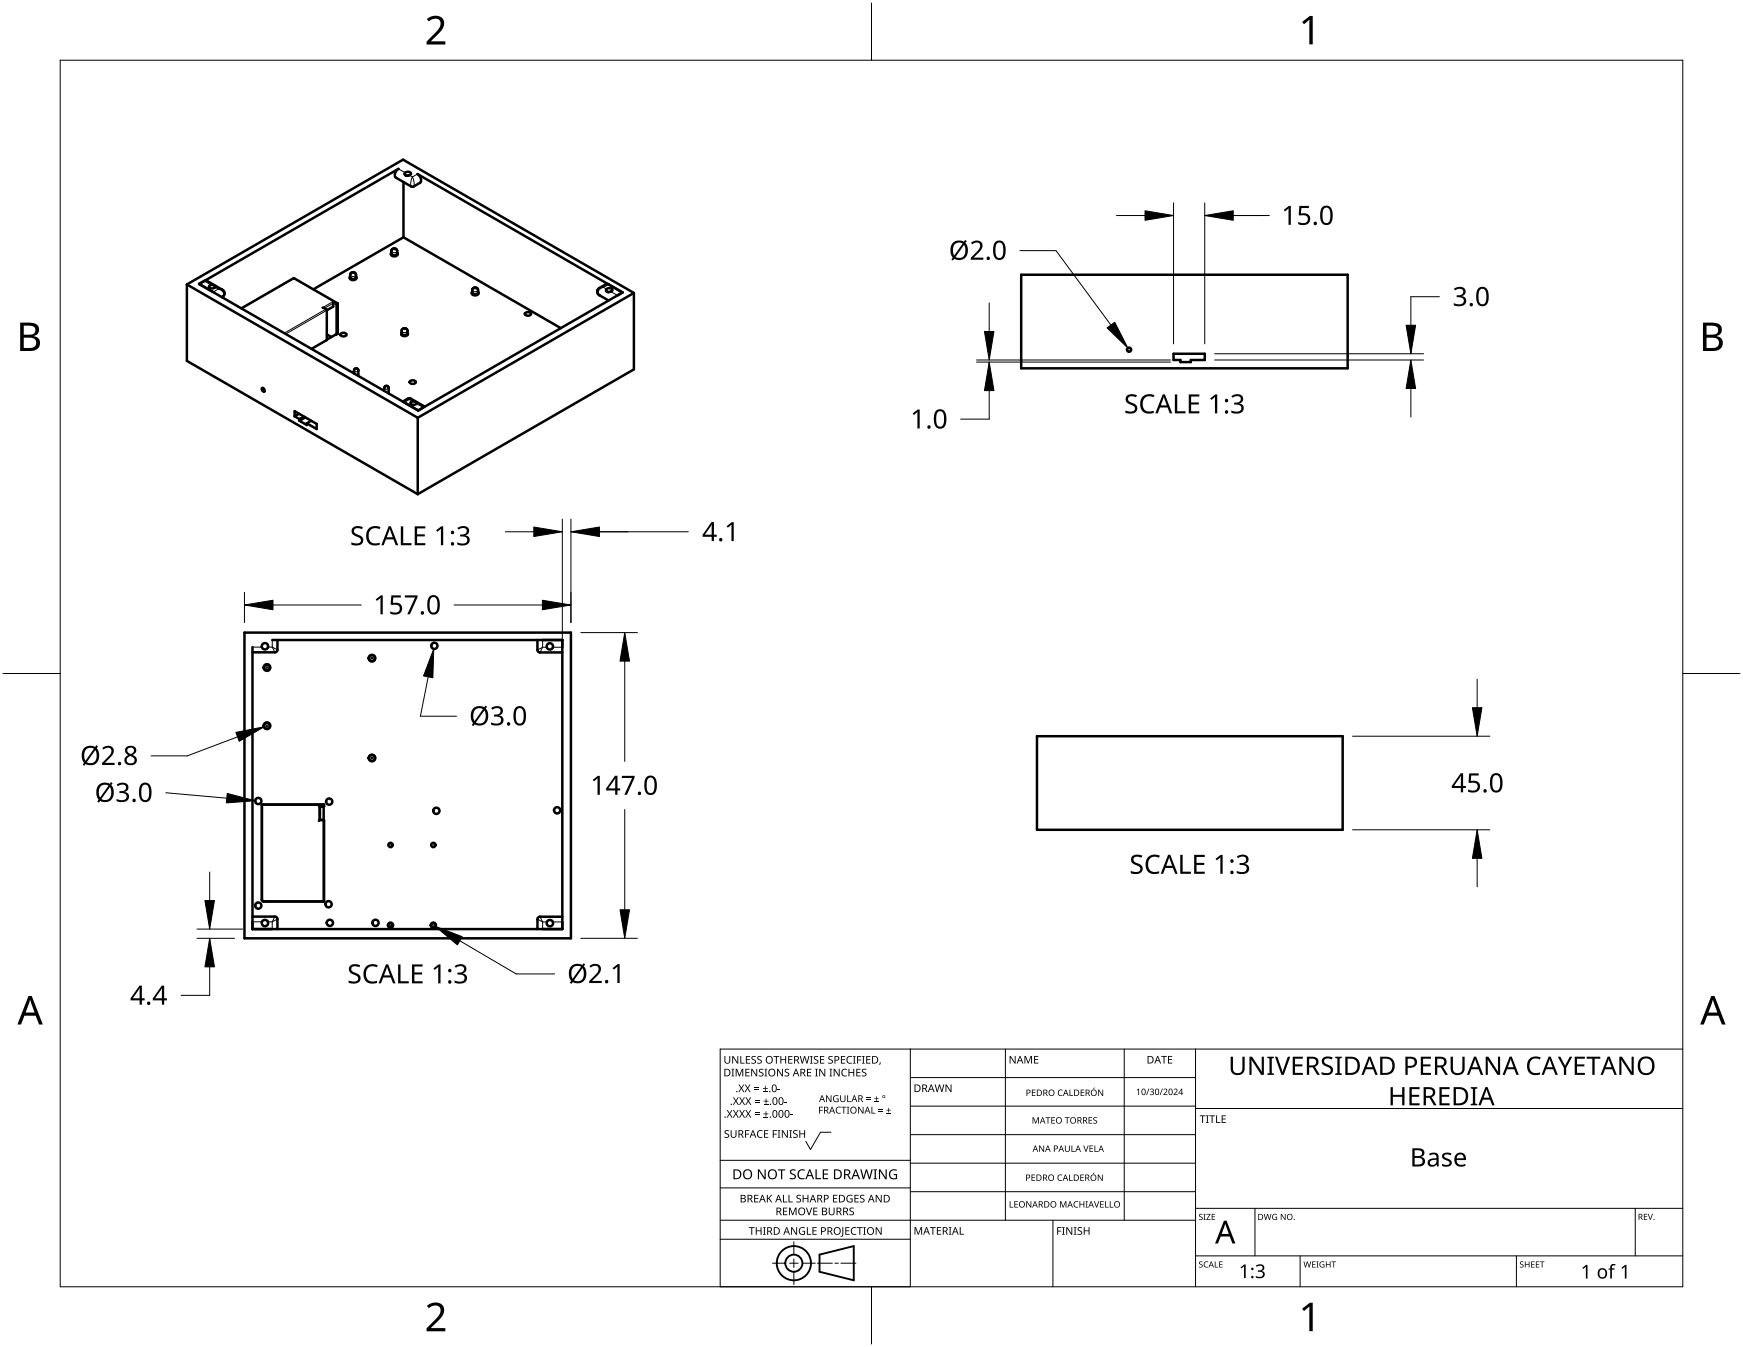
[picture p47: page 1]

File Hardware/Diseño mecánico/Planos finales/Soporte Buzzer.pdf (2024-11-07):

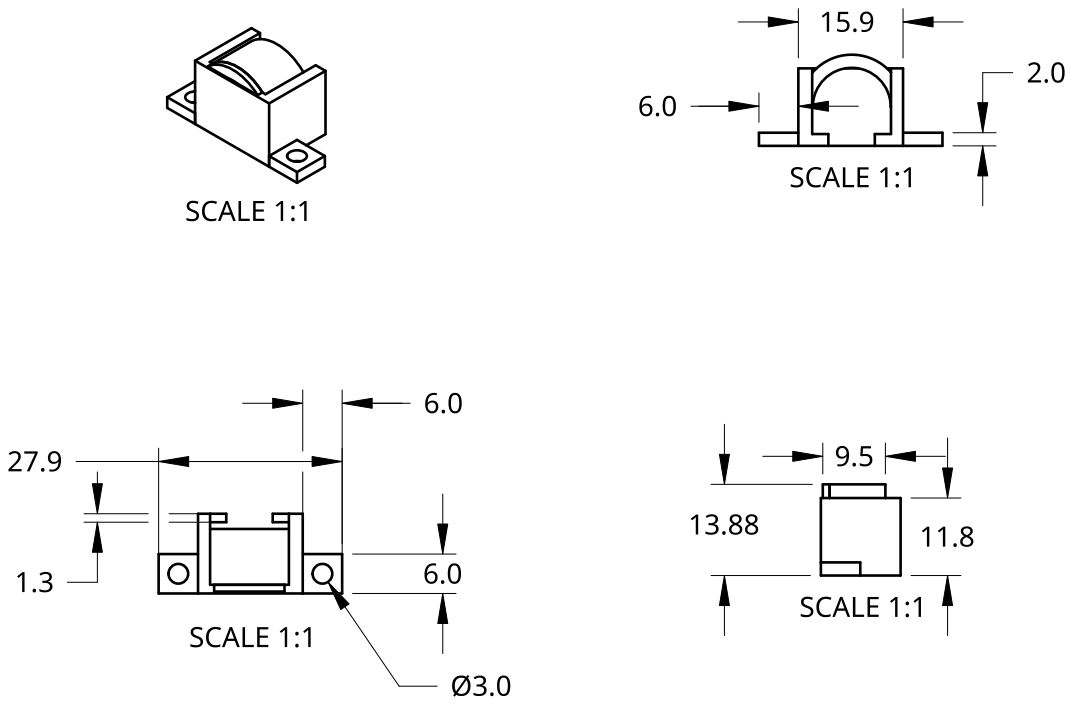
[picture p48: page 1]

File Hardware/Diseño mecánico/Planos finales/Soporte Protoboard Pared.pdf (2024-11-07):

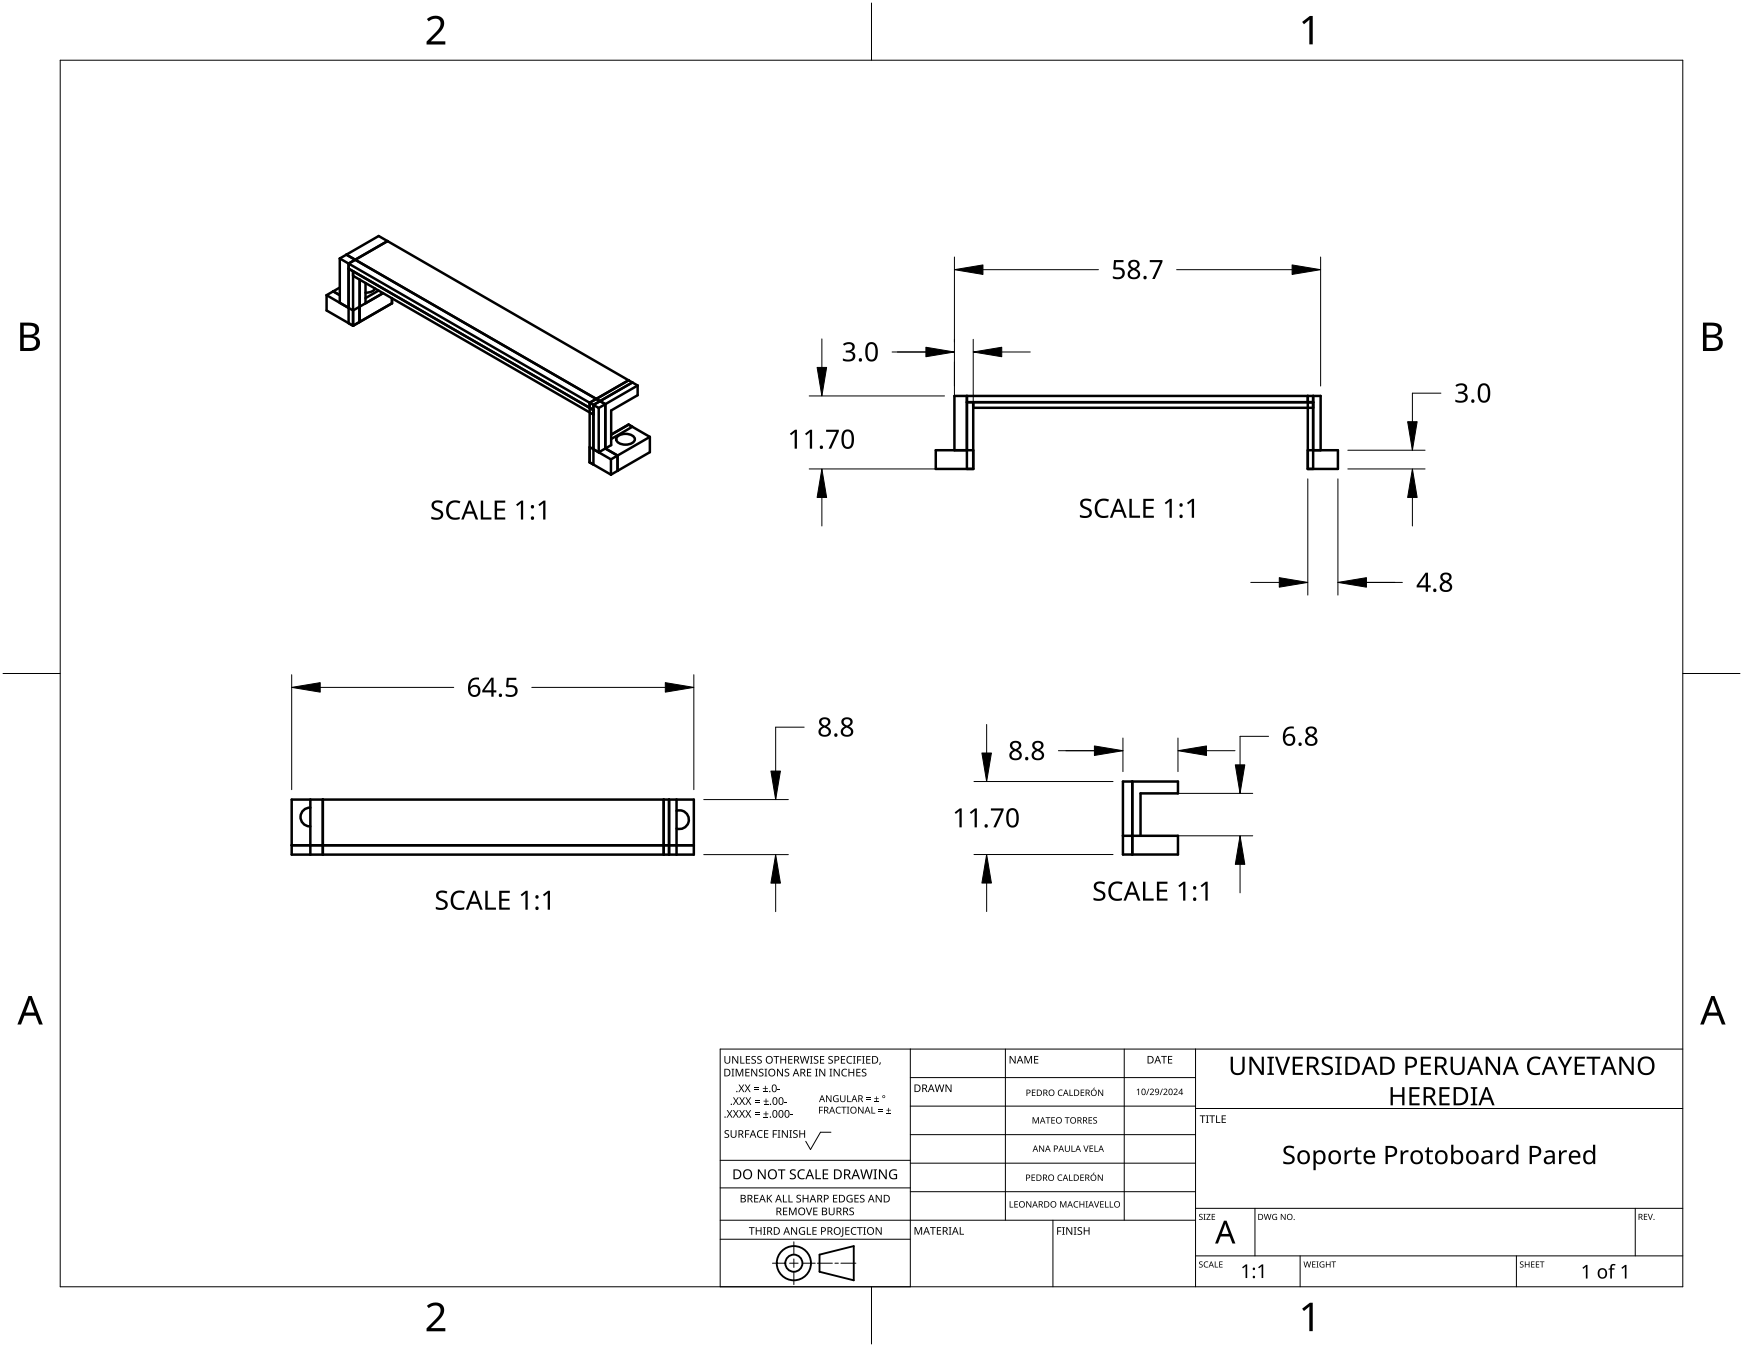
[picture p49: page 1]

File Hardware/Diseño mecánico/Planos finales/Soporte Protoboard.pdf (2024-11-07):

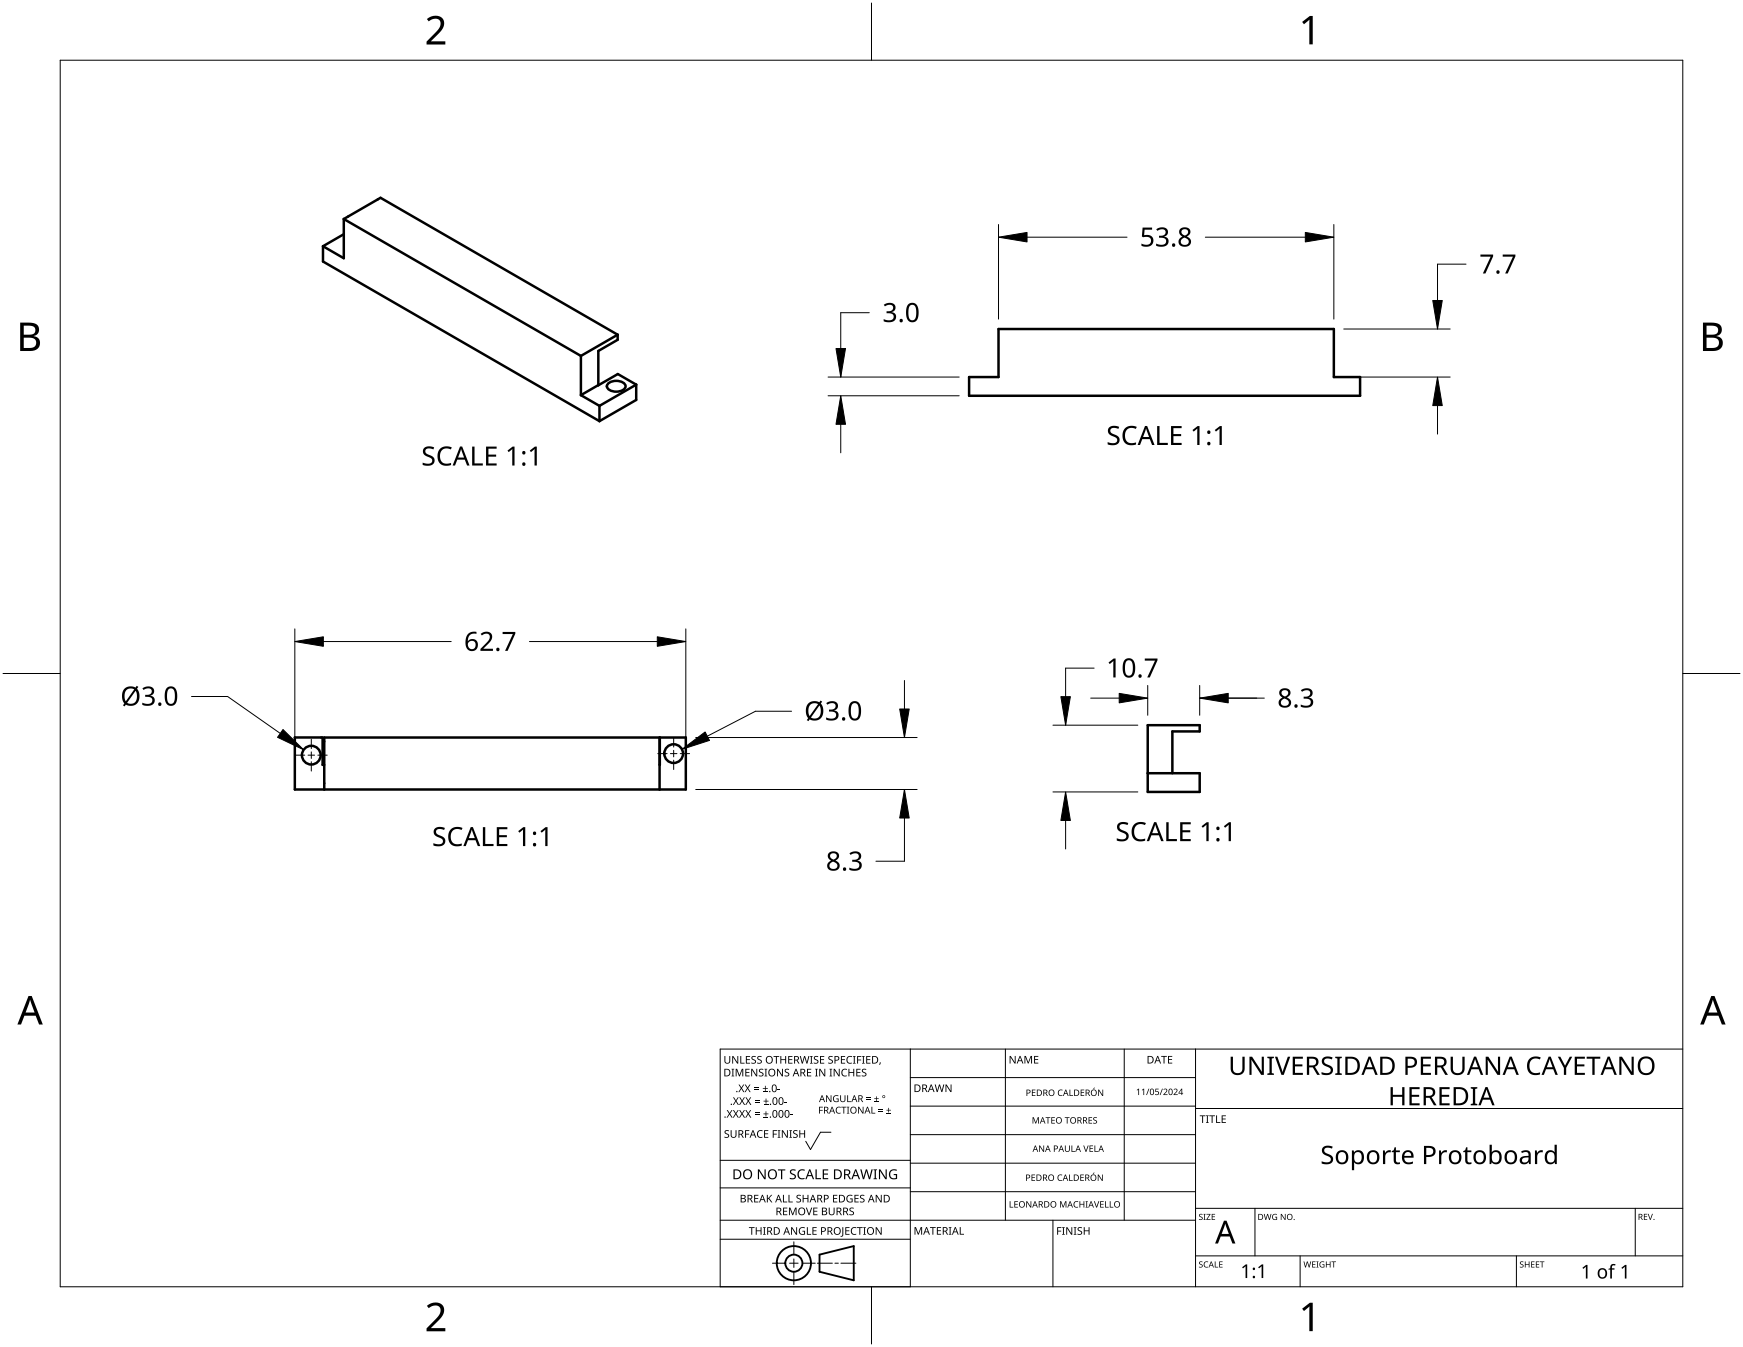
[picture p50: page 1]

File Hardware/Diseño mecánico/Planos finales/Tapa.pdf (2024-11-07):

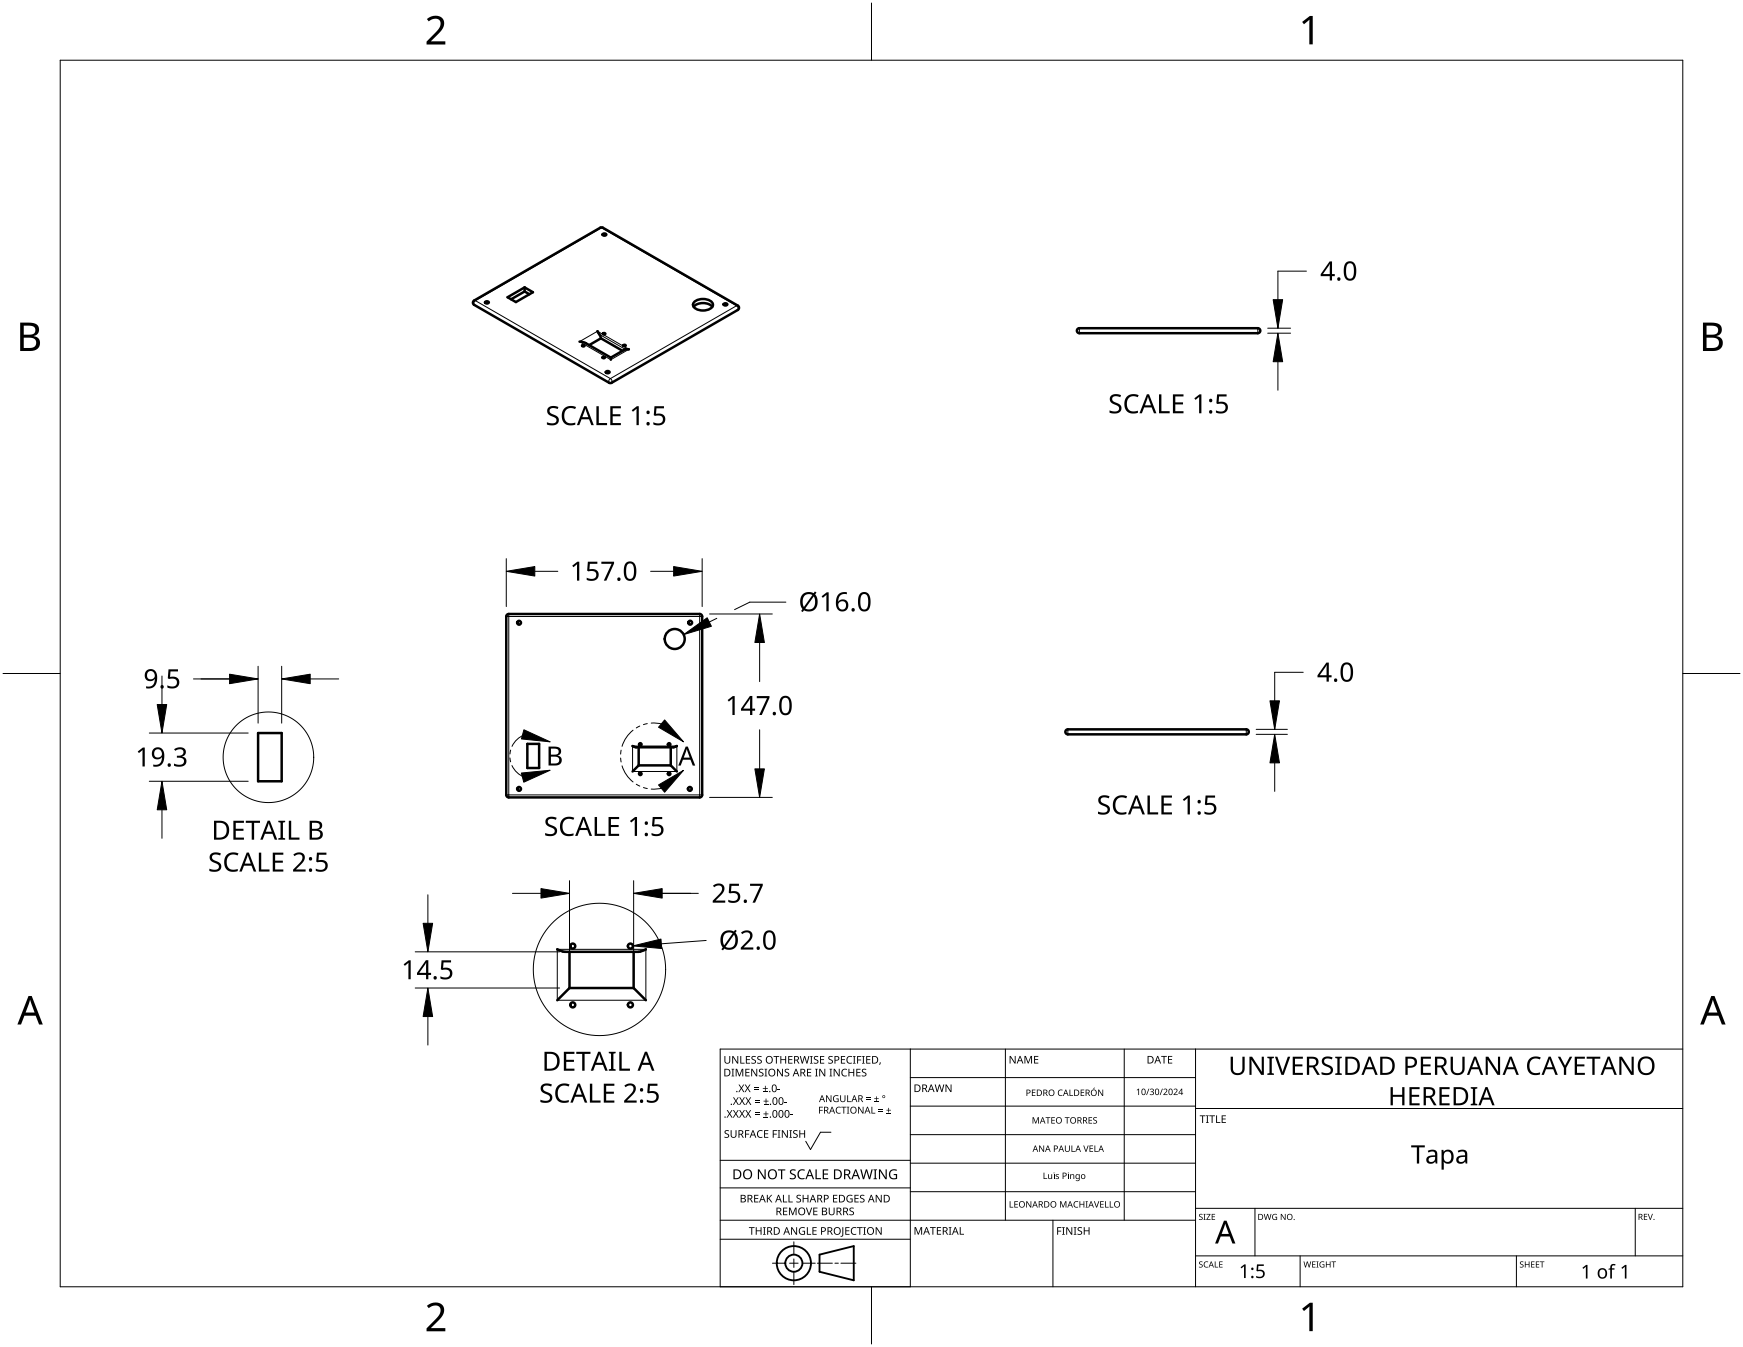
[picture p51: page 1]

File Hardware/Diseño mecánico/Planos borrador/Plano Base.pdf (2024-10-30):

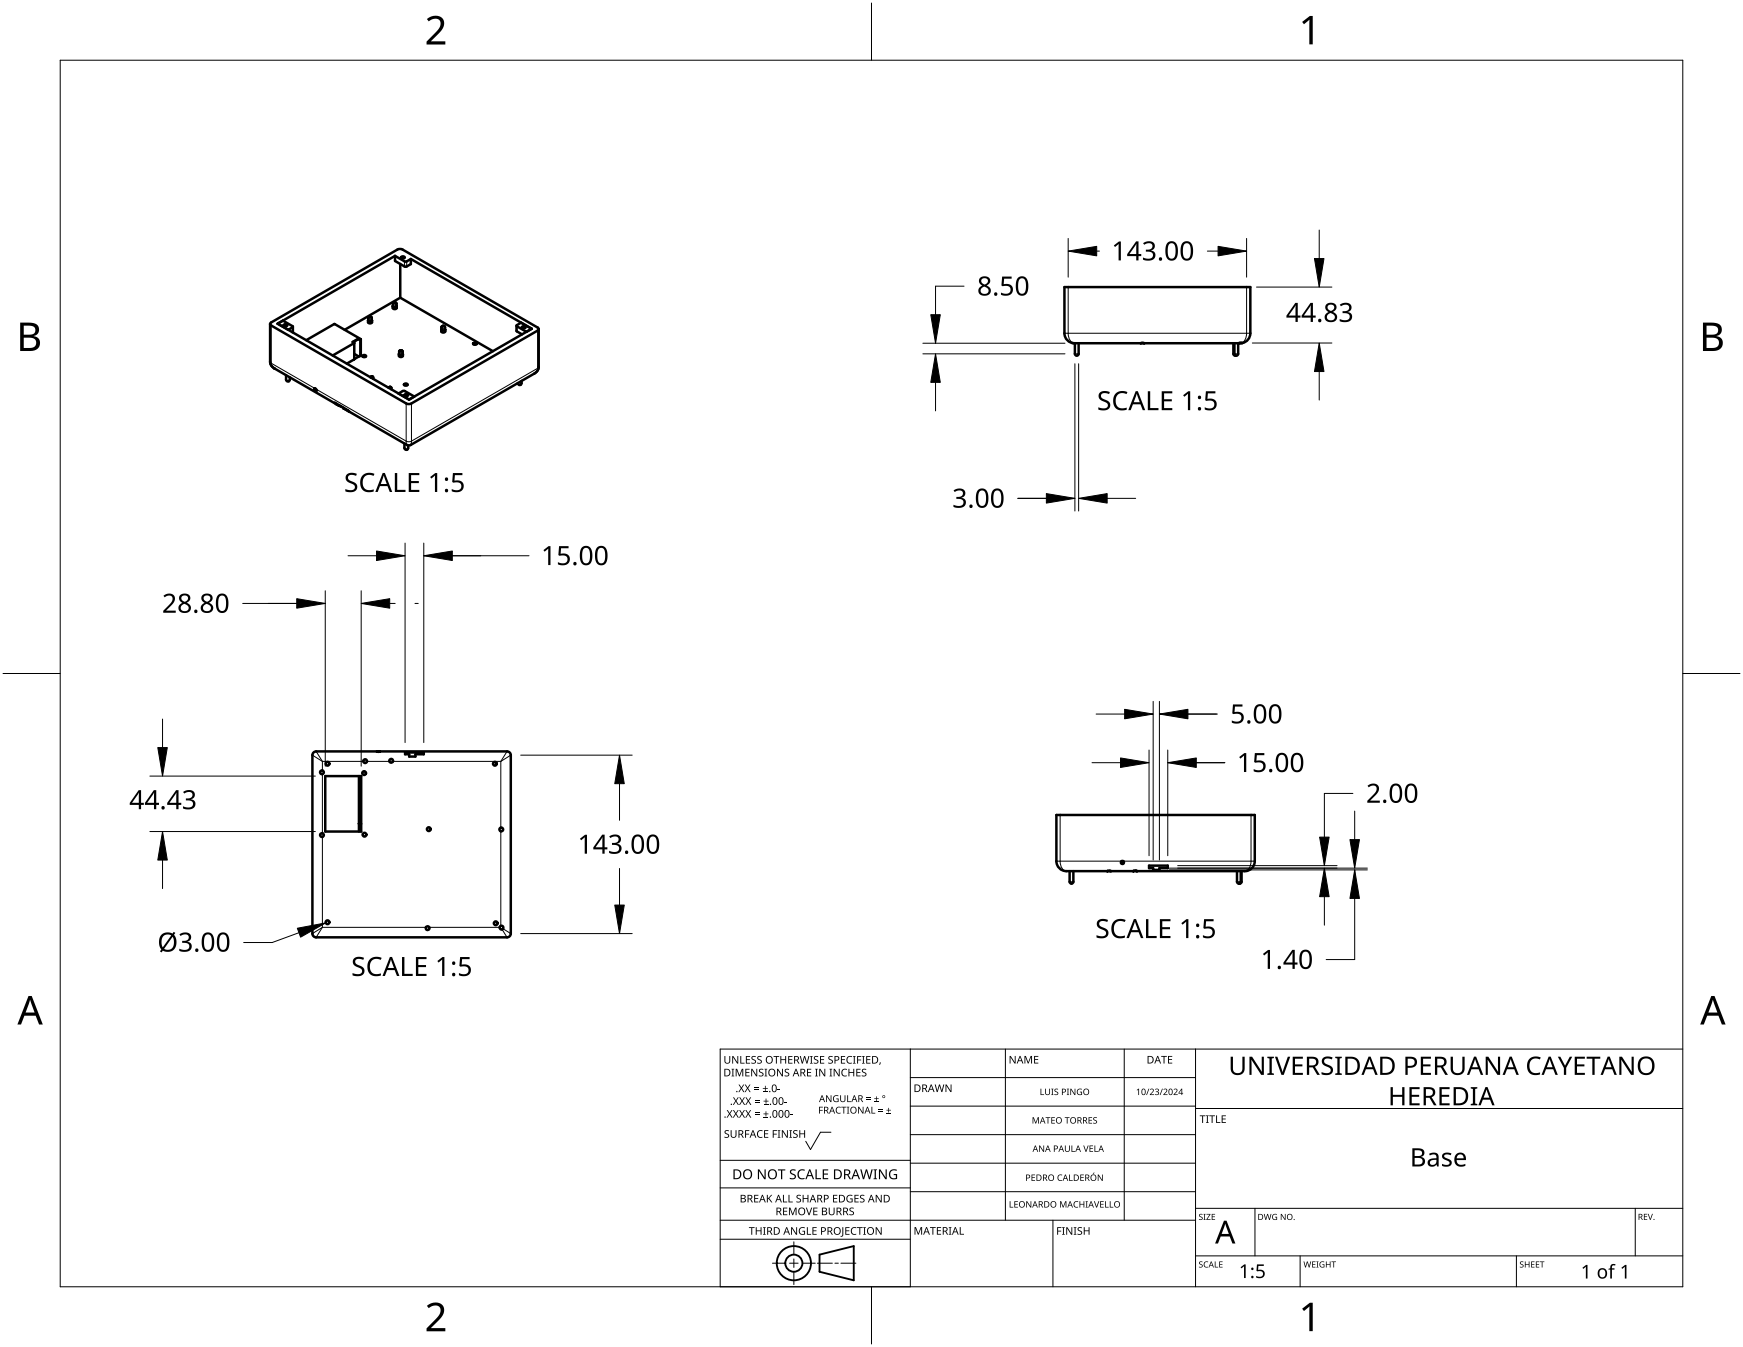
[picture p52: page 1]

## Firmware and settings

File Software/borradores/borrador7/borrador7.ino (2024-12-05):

#include "SSD1306Ascii.h"
#include "SSD1306AsciiAvrI2c.h"
#include <SD.h>
#include <math.h>

#define I2C_ADDRESS 0x3C
#define RST_PIN -1

File dataFile;
SSD1306AsciiAvrI2c oled;

const int pinSD = 10;
const int pinSensor = A0;
const int pinBuzzer = 5;
const float sensibilidadSensor = 0.005;
const int factorCalib = 1;
const float limiteVoltaje = 0.1;
unsigned long tiempoInicio = 0;
unsigned long duracionReporte = 10000;
unsigned long tiempoTranscurrido = 0;
bool cronometroActivo = false;
bool mostrandoReporte = false;

// Variables para PEF, FEV1, FVC
float flujoMaximo = 0; // PEF
float volumenFEV1 = 0; // FEV1
float volumenTotal = 0; // FVC

unsigned long ultimoTiempoOLED = 0;  
const unsigned long intervaloOLED = 1000; 

String nombreArchivo;

float voltajeReferencia = 0.0;

String obtenerNombreArchivo() {
  int numeroArchivo = 1;
  String nombreArchivo = "datos_" + String(numeroArchivo) + ".csv";

  // Recorremos los archivos existentes en la tarjeta SD para encontrar el último número usado
  while (SD.exists(nombreArchivo.c_str())) {
    numeroArchivo++;  // Incrementamos el número del archivo
    nombreArchivo = "datos" + String(numeroArchivo) + ".csv";  // Generamos el nuevo nombre de archivo
  }

  return nombreArchivo;
}

void mostrarReporte(float PEF, float FEV1, float FVC) {
  oled.setFont(Arial14);
  oled.clear();
  oled.println("Reporte:");

  oled.print("PEF: ");
  oled.print(PEF, 3);
  oled.println(" L/s");

  oled.print("FEV1: ");
  oled.print(FEV1, 3);
  oled.println(" L");

  oled.print("FVC: ");
  oled.print(FVC, 3);
  oled.println(" L");
}

void mostrarLungie() {
  oled.clear();
  oled.setFont(Arial_bold_14);
  oled.println(" ");
  oled.print("        LUNGIE");
}

void setup() {
  Serial.begin(9600);
  #if RST_PIN >= 0
    oled.begin(&Adafruit128x64, I2C_ADDRESS, RST_PIN);
  #else
    oled.begin(&Adafruit128x64, I2C_ADDRESS);
  #endif

  oled.clear();
  oled.setFont(Arial14);
  oled.print("Iniciando SD...");
  delay(1000);

  if (!SD.begin(pinSD)) {
    oled.clear();
    oled.print("Error tarjeta SD.");
    while (1);
  }
  oled.clear();
  oled.print("Tarjeta SD OK.");
  delay(1000);

  nombreArchivo = obtenerNombreArchivo();

  dataFile = SD.open(nombreArchivo.c_str(), FILE_WRITE);
  if (dataFile) {
    dataFile.println("Tiempo (s);Flujo(L/s);Volumen(L)");  // Cabecera
    dataFile.close();
    oled.clear();
    oled.print("Tabla de datos creada.");
    delay(1000);
  } else {
    oled.clear();
    oled.print("Error creando archivo.");
    while (1); // Detener si no se puede crear el archivo
  }

  float sumaVoltajes = 0.0;
  for (int i = 0; i < 5; i++) {
    float lectura = analogRead(pinSensor) * (5.0 / 1023.0); // Convertir a voltaje
    sumaVoltajes += lectura;
    delay(100); // Pequeño retraso entre lecturas
  }
  voltajeReferencia = sumaVoltajes / 5.0; // Promedio de las 5 lecturas
  Serial.print("Voltaje de referencia establecido: ");
  Serial.println(voltajeReferencia, 3);

  oled.clear();
  oled.print("Voltaje ref: ");
  oled.print(voltajeReferencia, 3);
  delay(2000);

  mostrarLungie();
  delay(5000);
}

void loop() {
  float voltajeProm = analogRead(A0) * (5.0 / 1023.0);
  voltajeProm -= voltajeReferencia;
  float presionProm = voltajeProm / (5 * sensibilidadSensor);
  float flujoProm = factorCalib * sqrt(presionProm); // Flujo en L/s

  Serial.print("Flujo: ");
  Serial.println(flujoProm, 3);
  Serial.print("Voltaje: ");
  Serial.println(voltajeProm, 3);

  if (voltajeProm > limiteVoltaje) {
    if (!cronometroActivo) {
      cronometroActivo = true;
      tiempoInicio = millis();
      flujoMaximo = 0;
      volumenFEV1 = 0;
      volumenTotal = 0;
      tone(pinBuzzer, 262, 500);
    }

    if (flujoProm > flujoMaximo) {
      flujoMaximo = flujoProm; // Actualiza el PEF
    }

    // Calcula el tiempo transcurrido
    tiempoTranscurrido = (millis() - tiempoInicio);

    // Sumar flujo al volumen total (FVC)
    volumenTotal += flujoProm * (1.0 / 1000.0); // Asumiendo delay de 1 ms para conversión a segundos

    // Sumar flujo al volumen FEV1 si estamos en el primer segundo
    if (tiempoTranscurrido <= 1000) {
      volumenFEV1 += flujoProm * (1.0 / 1000.0);
    }

    dataFile = SD.open(nombreArchivo.c_str(), FILE_WRITE);
    if (dataFile) {
      dataFile.print(tiempoTranscurrido / 1000.0);
      dataFile.print(";");
      dataFile.print(flujoProm, 3);
      dataFile.print(";");
      dataFile.println(volumenTotal, 3);
      dataFile.close();
    }

    if (millis() - ultimoTiempoOLED >= intervaloOLED) {
      ultimoTiempoOLED = millis();
      oled.clear();
      oled.setFont(Arial14);
      oled.print("Tiempo: ");
      oled.print(tiempoTranscurrido / 1000.0);
      oled.print(" s");
    }

  } else {
    if (cronometroActivo) {
      cronometroActivo = false;
      mostrandoReporte = true;
      mostrarReporte(flujoMaximo, volumenFEV1, volumenTotal);
      tiempoInicio = millis();
      tone(pinBuzzer, 262, 500);
    }
  }

  if (mostrandoReporte && millis() - tiempoInicio >= duracionReporte) {
    mostrandoReporte = false;
    mostrarLungie();
  }

  delay(10);
}

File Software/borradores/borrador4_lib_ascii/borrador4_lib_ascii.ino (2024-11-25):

#include "SSD1306Ascii.h"
#include "SSD1306AsciiAvrI2c.h"
#include <SD.h>

#define I2C_ADDRESS 0x3C
#define RST_PIN -1

SSD1306AsciiAvrI2c oled;

const int pinSD = 10;
const int pinSensor = A1;
const int pinBuzzer = A0;
const float limiteVoltaje = 2.5;
unsigned long tiempoInicio = 0;
unsigned long duracionReporte = 10000;
unsigned long tiempoTranscurrido = 0;
bool cronometroActivo = false;
bool mostrandoReporte = false;

float voltajeMaximo = 0;
float voltajeTotal = 0;
int contadorVoltajes = 0;

void mostrarReporte(float maxVoltaje, float promedioVoltaje) {

  oled.setFont(Arial14);
  oled.clear();
  oled.println("Reporte:");

  oled.print("Max: ");
  oled.print(maxVoltaje, 3);
  oled.println(" V");

  oled.print("Prom: ");
  oled.print(promedioVoltaje, 3);
  oled.print(" V");
}

void mostrarLungie() {

  oled.clear();
  oled.setFont(Arial_bold_14);
  oled.println(" ");
  oled.print("        LUNGIE");

}

int getStableReading(int A1) {
  long sum = 0;                   
  for (int i = 0; i < 10; i++) {  
    sum += analogRead(A1);        
    delay(10);                     
  }
  return sum / 10;                 
}

void setup() {

  Serial.begin(9600);
  #if RST_PIN >= 0
    oled.begin(&Adafruit128x64, I2C_ADDRESS, RST_PIN);
  #else // RST_PIN >= 0
    oled.begin(&Adafruit128x64, I2C_ADDRESS);
  #endif // RST_PIN >= 0

  oled.clear();
  oled.setFont(Arial14);
  oled.print("Iniciando SD...");
  delay(1000);

  if (!SD.begin(pinSD)) {
    oled.clear();
    oled.print("Error tarjeta SD.");
    while (1); // Detener si no se detecta la tarjeta
  }
  oled.clear();
  oled.print("Tarjeta SD OK.");
  delay(1000);

  mostrarLungie();
}

void loop() {
  
  int promedio = getStableReading(A1);
  float voltajeProm = promedio * (5.0/1023.0);

  Serial.print("Valor del sensor de presión: ");
  Serial.print(promedio);
  Serial.print(" - Voltaje: ");
  Serial.println(voltajeProm, 3);

  if (voltajeProm > limiteVoltaje) {
    if (!cronometroActivo) {
      // Inicia el cronómetro si aún no está activo
      cronometroActivo = true;
      tiempoInicio = millis(); // Guarda el tiempo actual como inicio
    }

    // Actualiza el voltaje máximo y total
    if (voltajeProm > voltajeMaximo) {
      voltajeMaximo = voltajeProm;
    }
    voltajeTotal += voltajeProm;
    contadorVoltajes++;

    // Calcula el tiempo transcurrido en segundos
    tiempoTranscurrido = (millis() - tiempoInicio) / 1000;

    // Actualiza la pantalla OLED con el cronómetro
    oled.clear();
    oled.setFont(Arial14);
    oled.print("Tiempo: ");
    oled.print(tiempoTranscurrido);
    oled.print(" s");
  } else {
    if (cronometroActivo) {
      // Detiene el cronómetro cuando el voltaje baja del límite
      cronometroActivo = false;
      tiempoTranscurrido = (millis() - tiempoInicio) / 1000;

      // Calcular el promedio de los voltajes
      float voltajePromedio = voltajeTotal / contadorVoltajes;

      // Mostrar el reporte durante 10 segundos
      mostrandoReporte = true;
      mostrarReporte(voltajeMaximo, voltajePromedio);
      tiempoInicio = millis();  // Reinicia el tiempo para el reporte
    }
  }

  // Limpiar la pantalla después de 10 segundos
  if (mostrandoReporte && millis() - tiempoInicio >= duracionReporte) {
    mostrandoReporte = false;
    mostrarLungie();  // Muestra de nuevo "LUNGIE" después del reporte
  }
  
  delay(1000);

}

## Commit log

2024-08-25 Agrego carpeta de Entregables
2024-08-26 Actualización de README
2024-08-26 Agrego carpeta de fotos
2024-09-04 Actualización de Entregable 2
2024-09-04 Agrego tabla de requerimientos
2024-09-04 Agrego propuesta de solución
2024-09-04 Actualizo tabla de requerimientos
2024-09-15 Actualización Diagrama de Ishikawa
2024-10-23 tabla de valoración 3
2024-10-28 Agrego carpetas de Hardware y Software
2024-10-28 Añado código de prueba arduino
2024-10-30 Fotos desarrollo arduino
2024-11-13 Actualización Entregable 8
    [Base.stl, Soporte Buzzer.stl, Soporte Protoboard.stl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]
2024-11-13 Organización carpeta Hardware
    [Base.stl, Soporte Buzzer.stl, Soporte Protoboard.stl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]
2024-11-24 Código de prueba lector SD
2024-11-26 Agrego video de prueba
